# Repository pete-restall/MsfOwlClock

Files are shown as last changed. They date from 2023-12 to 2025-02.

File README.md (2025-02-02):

# MSF Owl Clock
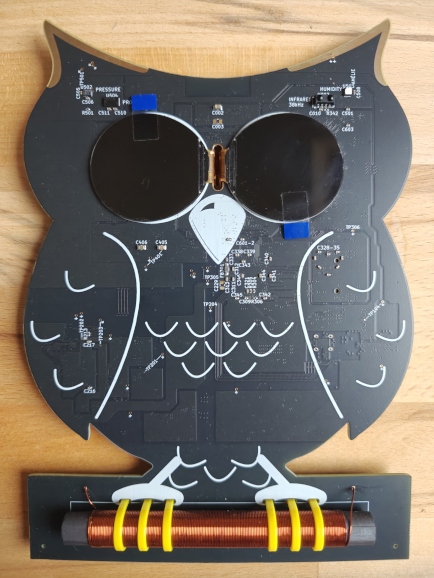
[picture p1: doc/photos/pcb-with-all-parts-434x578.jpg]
PCB
<span style="display:block;text-align:center"></span>

The board with the ferrite rod antenna and two TFT displays attached.

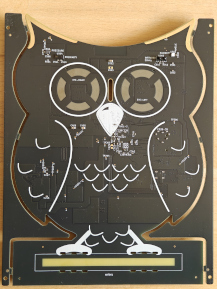
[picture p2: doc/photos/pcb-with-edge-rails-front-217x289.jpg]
Front of PCB
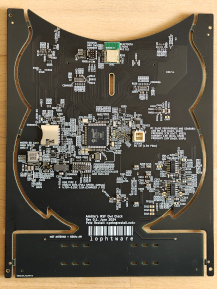
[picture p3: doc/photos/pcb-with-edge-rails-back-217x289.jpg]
Back of PCB
 

The above images are the boards as delivered from fabrication, not the end product.  Namely:
* The edge / tool rails need to be cut off to leave only the owl-shaped board
* A ferrite rod antenna (and tuning capacitors) need to be attached, creating a branch on which the owl perches (yellow tie-wraps for talons)
* Two TFT displays need to be secured in place for the eyes
* A base / stand needs to be 3D printed, which will also hold a speaker and its cavity

This project is a desk clock intended to synchronise with the [60kHz AM MSF](doc/datasheets/msf/msf.pdf) time signal that is broadcast by the UK's NPL using their [Anthorn Radio Station in Cumbria, England](https://www.npl.co.uk/msf-signal).

The [board schematics](src/schematics/msf-owl-clock.pdf) and [PCB fab files](src/pcb-fab/) were created in KiCAD.  [Firmware](src/firmware/) will, no doubt, be a very long-running part of the project (as usually seems to happen...)

The board consists of:
* A [PIC32CX1025SG41100](doc/datasheets/mcu/PIC32CX1025SG41100-datasheet-DS60001715.pdf) ARM Cortex M4F:
  * M-profile ARM v7 CPU running up to 120MHz
  * 1MiB flash
  * 256KiB SRAM
  * 8KiB backup SRAM
  * 1Msps 12-bit ADC
  * 1Msps 12-bit DAC
* Two multiplexed QSPI [360x360 Circular TFTs](doc/datasheets/tft/buydisplay-ER-TFT1.32-1.pdf) for the eyes
* A USB Type-C connector with USB PD / charger detection and USB2.0 Full Speed data
* A Micro SD Card connector
* An [IS31AP4991A](doc/datasheets/opamps/IS31AP4991A-SLS2-TR.pdf) audio amplifier / speaker driver (the speaker and cavity will be built into a 3D-printed base / stand)
* A [BC805M](doc/datasheets/bluetooth/BC805M.pdf) 2.4GHz Bluetooth / BLE 5.2 Module running an [nRF52805](doc/datasheets/bluetooth/nRF52805_PS_v1.4.pdf) ARM Cortex M4
* A range of I<sup>2</sup>C sensors:
  * A [DPS310XTSA1](doc/datasheets/sensors/pressure/DPS310XTSA1.pdf) Pressure Sensor to create a barometer
  * A [HDC3022](doc/datasheets/sensors/humidity/HDC3022.pdf) Humidity Sensor for measuring humidity and temperature
  * A [VL6180V1NR](doc/datasheets/sensors/proximity/VL6180V1NR-1.pdf) Proximity Sensor to allow power-saving mode when nobody is nearby / at night
  * A [TSOP75338TT](doc/datasheets/sensors/infrared/TSOP75338TT.pdf) 38kHz Infrared Receiver to allow remote control

The board is shaped as an owl as it is intended for my daughter, a little girl that _really_ likes owls.  I hope it will spark some curiosity and prompt her to enquire how everyday items and systems around her work, things that most people take for granted or do not even notice.

Obviously it's also for me to play with, as and when I get the time.

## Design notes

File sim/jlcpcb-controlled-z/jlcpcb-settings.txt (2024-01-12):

***
*** These settings correlate well with JLCPCB's impedance calculations for
*** stackup JLC04161H-7628:
***     https://jlcpcb.com/pcb-impedance-calculator/
***
*** The laminate parameters used can be found here:
***     https://jlcpcb.com/help/article/263-User-Guide-to-the-JLCPCB-Impedance-Calculator
***
*** A copy is also in the doc/datasheets/pcb directory.
***

-------------------------------

2D Impedance Calculator Program

Version 0.2.1.88

Time: Fri Jan 12 10:31:19 2024

GPL Version 2.0

-------------------------------

Simulation pix map 416 pixels high by 900 pixels wide.

1124224 bytes allocated for bmp.

Writing BMP file:

mdtlc_24001238880.bmp

INPUT PARAMETERS:

      Layer             Thick   Specifications 

       Solder Mask Top   1.20    Opening w=0.0  offset=0.0

        Signal Layer 1   1.60  Width=6.0  Etchback=0.16

      Laminate Layer 2   8.60    Resin Content  49.0% 4.0-4.4 

   Copper Plane Bottom   0.60    Opening w=0.0  offset=0.0

      Layer             Thick   Er    Loss Tangent

               Air top  29.60  1.00    0.00000

       Solder Mask Top   1.20  3.80    0.00200

        Signal Layer 1   1.60  4.20    0.00120

      Laminate Layer 2   8.60  4.20    0.00120

   Copper Plane Bottom   0.60  3.99

 Rdc_trace_1= 72.63  milliohms/in 20C

 DC resistance by pixel count:

 Rdc_trace_1=  72.511 milliohm/in.

 C          =   2.044 pF/in        L =  10.712 nH/in.

 Er         =   3.050       Loss_tan =   0.00113

 Zo         =  72.396 Ohms     Delay = 147.958 ps/in.

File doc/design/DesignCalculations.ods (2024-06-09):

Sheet: Capacitors
 |  |  | GRM21BR71A106KA73L | GRM155Z71A105KE01 | GRM155Z71A105KE01J | CL10B225KP8NNNC | CL05B104KA5NNNC | CL05A475MP5NRN
Capacitance
Nominal | 4.7 |  | 10 | 4.7 | 1 | 2.2 | 100 | 4.7
Nominal Adjusted for DC Bias | 1.88 | Look at the datasheet graphs for this; dependent on bias voltage and physical size | 6.83uF@3.3V, 4.73uF@5V | 3.972uF@3.3V, 3.212uF@5V | 0.598uF@3.3V | 1.95uF@3.3V | 92nF@5V | 1.88uF@3.3V
Min (-) Initial Tolerance (%) | 20.00% |  | 10.00% | 10.00% | 0.1 | 0.1 | 0.1 | 0.2
Max (+) Initial Tolerance (%) | 20.00% |  | 10.00% | 10.00% | 0.1 | 0.1 | 0.1 | 0.2
Min (-) Temperature Coefficient (%) | 15.00% | X7R and X5R are +/- 15% | 15.00% | 15.00% | 0.15 | 0.15 | 0.15 | 0.15
Max (+) Temperature Coefficient (%) | 15.00% |  | 15.00% | 15.00% | 0.15 | 0.15 | 0.15 | 0.15
Min Initial Capacitance | 1.504 |  | 6.147 | 3.5748 | 0.5382 | 1.755 | 82.8 | 1.504
Max Initial Capacitance | 2.256 |  | 7.513 | 4.3692 | 0.6578 | 2.145 | 101.2 | 2.256
Min Capacitance | 1.222 |  | 5.1225 | 2.979 | 0.4485 | 1.4625 | 69 | 1.222
Max Capacitance | 2.538 |  | 8.5375 | 4.965 | 0.7475 | 2.4375 | 115 | 2.538
Leakage Current
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

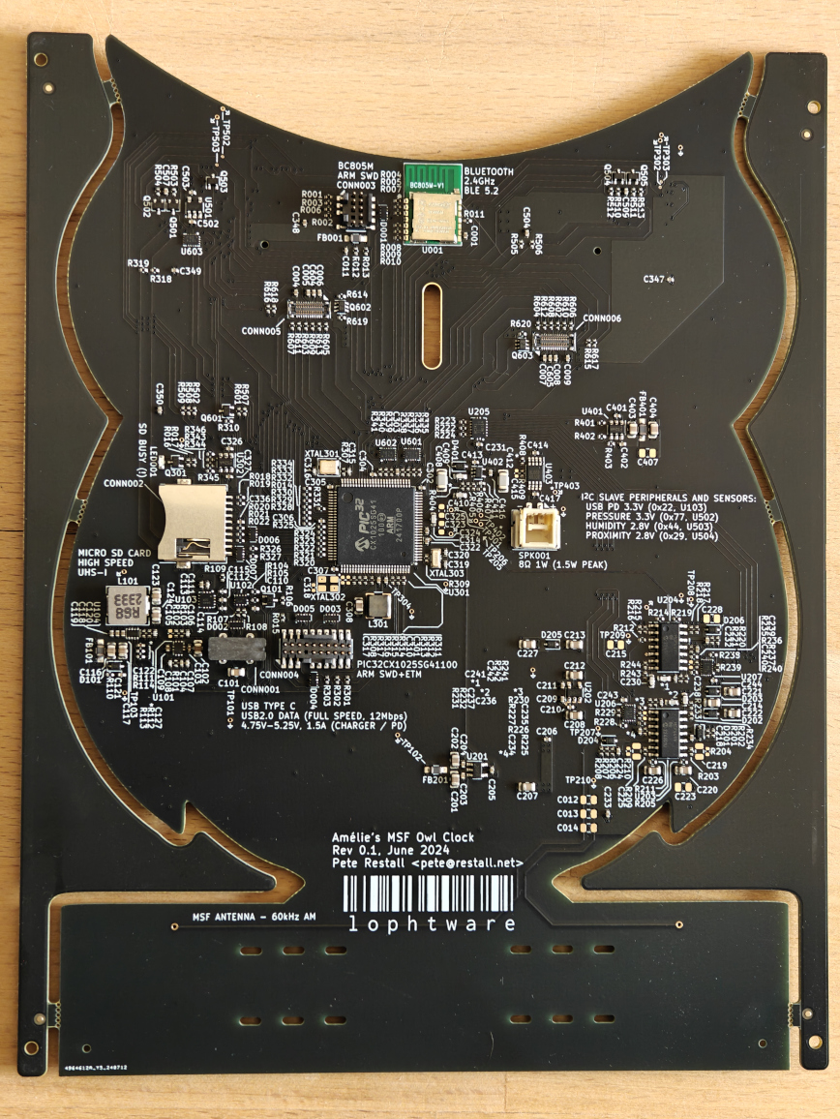
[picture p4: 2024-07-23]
doc/photos/pcb-with-edge-rails-back-868x1156.jpg

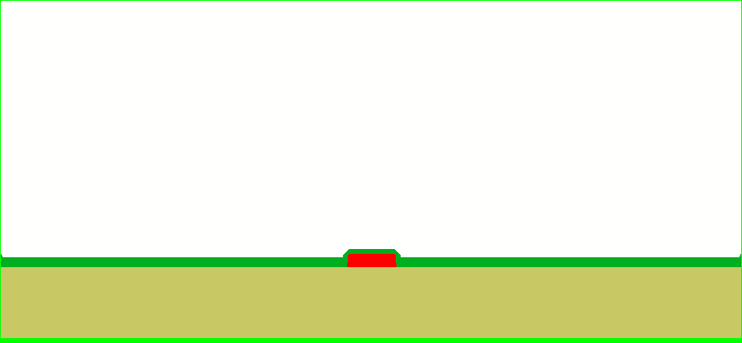
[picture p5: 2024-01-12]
sim/jlcpcb-controlled-z/6mil-single-microstrip.bmp

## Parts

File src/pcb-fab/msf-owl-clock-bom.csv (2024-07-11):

Designators | Value | Footprint | Package | Label | Manufacturer | Comment | Quantity | Description
C001, C004, C005, C006, C007, C008, C009, C010, C109, C110, C112, C113, C118, C119, C120, C121, C203, C204, C205, C206, C209, C210, C211, C216, C217, C218, C224, C231, C232, C233, C234, C239, C243, C244, C301, C302, C303, C304, C305, C306, C307, C309, C310, C311, C312, C313, C314, C322, C326, C327, C328, C329, C330, C331, C332, C333, C334, C335, C336, C337, C338, C339, C340, C341, C342, C343, C344, C345, C346, C347, C348, C349, C350, C401, C402, C413, C414, C416, C417, C501, C502, C503, C504, C505, C506, C507, C508, C509, C510, C511, C601, C602, C603, C604, C605 | 4.7μF | unpolarised-nominal-0402-1005 | 0402 | 4.7μF±20% 10V X5R | Samsung | CL05A475MP5NRNC | 95 | CL05A475MP5NRNC 4.7μF±20% 10V X5R 4.7μF 0402 Samsung
C002, C116, C117, C123, C124, C201, C202, C207, C208, C212, C213, C214, C220, C221, C222, C226, C227, C308, C403, C404, C405, C406 | 22μF | unpolarised-nominal-0805-2012 | 0805 | 22μF±20% 10V X5R | Samsung | CL21A226MPQNNN | 22 | CL21A226MPQNNN 22μF±20% 10V X5R 22μF 0805 Samsung
C230, C238, C409, C410 | 4.7nF | unpolarised-nominal-0603-1608 | 0603 | 4.7nF±5% 10V C0G | Murata | GCM1885C1H472GA16D | 4 | GCM1885C1H472GA16D 4.7nF±5% 10V C0G 4.7nF 0603 Murata
C011, C107, C321 | 100nF | unpolarised-nominal-0402-1005 | 0402 | 100nF±20% 10V X5R | Samsung | CL05B104KA5NNNC | 3 | CL05B104KA5NNNC 100nF±20% 10V X5R 100nF 0402 Samsung
C103, C104, C111 | 100nF | unpolarised-nominal-0402-1005 | 0402 | 100nF±20% 25V X5R | Samsung | CL05B104KA5NNNC | 3 | CL05B104KA5NNNC 100nF±20% 25V X5R 100nF 0402 Samsung
C236, C241, C324 | 4.7nF | unpolarised-nominal-0603-1608 | 0603 | 4.7nF±2% 10V C0G | Yageo | GCM1885C1H472GA16D | 3 | GCM1885C1H472GA16D 4.7nF±2% 10V C0G 4.7nF 0603 Murata
C101, C102 | 4.7μF | unpolarised-nominal-0805-2012 | 0805 | 4.7μF±10% 25V X5R | Samsung | CL21A475KAQNNNE | 2 | CL21A475KAQNNNE 4.7μF±10% 25V X5R 4.7μF 0805 Samsung
C114, C115 | 470pF | unpolarised-nominal-0402-1005 | 0402 | 470pF±10% 25V C0G | Murata | GCM1555C1H471FA16D | 2 | GCM1555C1H471FA16D 470pF±10% 25V C0G 470pF 0402 Murata
C237, C242 | 470pF | unpolarised-nominal-0402-1005 | 0402 | 470pF±2% 10V C0G | Murata | GCM1555C1H471FA16D | 2 | GCM1555C1H471FA16D 470pF±2% 10V C0G 470pF 0402 Murata
C315, C316 | 13pF | unpolarised-nominal-0402-1005 | 0402 | 13pF±1% 10V C0G | Murata | GJM1555C1H130FB01D | 2 | GJM1555C1H130FB01D 13pF±1% 10V C0G 13pF 0402 Murata
C319, C320 | 16pF | unpolarised-nominal-0402-1005 | 0402 | 16pF±1% 10V C0G | Murata | GCM1555C1H160FA16D | 2 | GCM1555C1H160FA16D 16pF±1% 10V C0G 16pF 0402 Murata
C408, C412 | 100nF | unpolarised-nominal-1206-3216 | 1206 | 100nF±5% 10V C0G | Murata | GRM3195C1H104JA05D | 2 | GRM3195C1H104JA05D 100nF±5% 10V C0G 100nF 1206 Murata
C106 | 39pF | unpolarised-nominal-0402-1005 | 0402 | 39pF±10% 10V X5R | Yageo | CC0402JRNPO9BN390 | 1 | CC0402JRNPO9BN390 39pF±10% 10V X5R 39pF 0402 Yageo
C108 | 100pF | unpolarised-nominal-0402-1005 | 0402 | 100pF±10% 10V X5R | Cal-Chip | GMC04CG101G50NT | 1 | GMC04CG101G50NT 100pF±10% 10V X5R 100pF 0402 Cal-Chip
C122 | 47nF | unpolarised-nominal-0402-1005 | 0402 | 47nF±10% 10V X5R | Vishay | VJ0402Y473KXQCW1BC | 1 | VJ0402Y473KXQCW1BC 47nF±10% 10V X5R 47nF 0402 Vishay
C127 | 10pF | unpolarised-nominal-0402-1005 | 0402 | 10pF±5% 10V C0G | Würth Elektronik | 885012005007 | 1 | 885012005007 10pF±5% 10V C0G 10pF 0402 Würth Elektronik
C411 | 22pF | unpolarised-nominal-0402-1005 | 0402 | 22pF±5% 10V C0G | Murata | GCM1555C1H220FA16D | 1 | GCM1555C1H220FA16D 22pF±5% 10V C0G 22pF 0402 Murata
R104, R105, R106, R110, R111, R222, R223, R224, R310, R326, R327, R342, R343, R344, R401, R402, R501, R502, R507, R508, R509, R512, R513, R601, R602, R603, R604, R605, R606, R607, R608, R609, R610, R611, R612, R613, R614, R615, R616, R617, R618 | 33kΩ | nominal-0402-1005 | 0402 | 33kΩ±1% 0.0625W | Walsin | WR04X3302FTL | 41 | WR04X3302FTL 33kΩ±1% 0.0625W 33kΩ 0402 Walsin
R004, R005, R007, R008, R009, R010, R011, R018, R019, R020, R021, R022, R311, R312, R313, R314, R315, R316, R317, R320, R321, R322, R323, R324, R325, R330, R331, R332, R333, R334 | 43Ω | nominal-0402-1005 | 0402 | 43Ω±1% 0.0625W | Yageo | RC0402FR-0743RL | 30 | RC0402FR-0743RL 43Ω±1% 0.0625W 43Ω 0402 Yageo
R002, R003, R006, R012, R301, R302, R303, R304 | 10kΩ | nominal-0402-1005 | 0402 | 10kΩ±1% 0.0625W | Walsin | WR04X1002FTL | 8 | WR04X1002FTL 10kΩ±1% 0.0625W 10kΩ 0402 Walsin
R212, R213, R215, R216, R217, R218 | 2.49kΩ | nominal-0402-1005 | 0402 | 2.49kΩ±0.1% 0.0625W | Yageo | RT0402BRD072K49L | 6 | RT0402BRD072K49L 2.49kΩ±0.1% 0.0625W 2.49kΩ 0402 Yageo
R318, R319, R340, R341, R505, R506 | 1.8kΩ | nominal-0402-1005 | 0402 | 1.8kΩ±1% 0.0625W | Yageo | RC0402FR-071K8L | 6 | RC0402FR-071K8L 1.8kΩ±1% 0.0625W 1.8kΩ 0402 Yageo
R013, R014, R103, R305, R306 | 1kΩ | nominal-0402-1005 | 0402 | 1kΩ±1% 0.0625W | Walsin | WR04X1001FTL | 5 | WR04X1001FTL 1kΩ±1% 0.0625W 1kΩ 0402 Walsin
R102, R203, R209, R307, R309 | 0Ω | nominal-0402-1005 | 0402 | 0Ω±1% 0.0625W | Yageo | RC0402FR-070RL | 5 | RC0402FR-070RL 0Ω±1% 0.0625W 0Ω 0402 Yageo
R201, R202, R208, R220, R221 | 4.99kΩ | nominal-0402-1005 | 0402 | 4.99kΩ±0.1% 0.0625W | Yageo | RT0402BRD074K99L | 5 | RT0402BRD074K99L 4.99kΩ±0.1% 0.0625W 4.99kΩ 0402 Yageo
R335, R336, R337, R338, R339 | 41.2Ω | nominal-0402-1005 | 0402 | 41.2Ω±1% 0.0625W | Yageo | RC0402FR-0741R2L | 5 | RC0402FR-0741R2L 41.2Ω±1% 0.0625W 41.2Ω 0402 Yageo
R001, R015, R328, R329 | 330Ω | nominal-0402-1005 | 0402 | 330Ω±1% 0.0625W | Walsin | WR04X3300FTL | 4 | WR04X3300FTL 330Ω±1% 0.0625W 330Ω 0402 Walsin
R113, R404, R408, R409 | 19.6kΩ | nominal-0402-1005 | 0402 | 19.6kΩ±1% 0.0625W | Walsin | WR04X1962FTL | 4 | WR04X1962FTL 19.6kΩ±1% 0.0625W 19.6kΩ 0402 Walsin
R503, R504, R510, R511 | 100Ω | nominal-0402-1005 | 0402 | 100Ω±1% 0.0625W | Walsin | WR04X1000FTL | 4 | WR04X1000FTL 100Ω±1% 0.0625W 100Ω 0402 Walsin
R225, R227, R237 | 390Ω | nominal-0402-1005 | 0402 | 390Ω±1% 0.0625W | Yageo | RT0402BRD07390RL | 3 | RT0402BRD07390RL 390Ω±1% 0.0625W 390Ω 0402 Yageo
R229, R235, R239 | 2.49kΩ | nominal-0402-1005 | 0402 | 2.49kΩ±1% 0.0625W | Yageo | RT0402BRD072K49L | 3 | RT0402BRD072K49L 2.49kΩ±1% 0.0625W 2.49kΩ 0402 Yageo
R016, R017 | 390Ω | nominal-0402-1005 | 0402 | 390Ω±1% 0.0625W | Yageo | RC0402FR-07390RL | 2 | RC0402FR-07390RL 390Ω±1% 0.0625W 390Ω 0402 Yageo
R107, R108 | 2.2Ω | nominal-0402-1005 | 0402 | 2.2Ω±1% 0.0625W | Vishay | RMCF0402FT2R20 | 2 | RMCF0402FT2R20 2.2Ω±1% 0.0625W 2.2Ω 0402 Vishay
R109, R114 | 5.1kΩ | nominal-0402-1005 | 0402 | 5.1kΩ±1% 0.0625W | Walsin | WR04X5101FTL | 2 | WR04X5101FTL 5.1kΩ±1% 0.0625W 5.1kΩ 0402 Walsin
R205, R211 | 27Ω | nominal-0402-1005 | 0402 | 27Ω±1% 0.0625W | TE Connectivity | CPF0402B27RE1 | 2 | CPF0402B27RE1 27Ω±1% 0.0625W 27Ω 0402 TE Connectivity
R206, R207 | 4.3kΩ | nominal-0402-1005 | 0402 | 4.3kΩ±0.1% 0.0625W | Yageo | RT0402BRD074K3L | 2 | RT0402BRD074K3L 4.3kΩ±0.1% 0.0625W 4.3kΩ 0402 Yageo
R214, R219 | 68Ω | nominal-0402-1005 | 0402 | 68Ω±0.1% 0.0625W | Yageo | RT0402BRD0768RL | 2 | RT0402BRD0768RL 68Ω±0.1% 0.0625W 68Ω 0402 Yageo
R228, R238 | 1.24kΩ | nominal-0402-1005 | 0402 | 1.24kΩ±1% 0.0625W | Yageo | RT0402BRD071K24L | 2 | RT0402BRD071K24L 1.24kΩ±1% 0.0625W 1.24kΩ 0402 Yageo
R230, R240 | 4.99kΩ | nominal-0402-1005 | 0402 | 4.99kΩ±1% 0.0625W | Yageo | RT0402BRD074K99L | 2 | RT0402BRD074K99L 4.99kΩ±1% 0.0625W 4.99kΩ 0402 Yageo
R231, R241 | 4.12kΩ | nominal-0402-1005 | 0402 | 4.12kΩ±0.1% 0.0625W | Yageo | RT0402BRD074K12L | 2 | RT0402BRD074K12L 4.12kΩ±0.1% 0.0625W 4.12kΩ 0402 Yageo
R232, R242 | 64.9Ω | nominal-0402-1005 | 0402 | 64.9Ω±0.1% 0.0625W | TE Connectivity | RP73PF1E64R9BTD | 2 | RP73PF1E64R9BTD 64.9Ω±0.1% 0.0625W 64.9Ω 0402 TE Connectivity
R233, R243 | 49.9kΩ | nominal-0402-1005 | 0402 | 49.9kΩ±0.1% 0.0625W | Yageo | RT0402BRD0749K9L | 2 | RT0402BRD0749K9L 49.9kΩ±0.1% 0.0625W 49.9kΩ 0402 Yageo
R234, R244 | 0Ω | nominal-0402-1005 | 0402 | 0Ω±0.1% 0.0625W | Yageo | RC0402FR-070RL | 2 | RC0402FR-070RL 0Ω±0.1% 0.0625W 0Ω 0402 Yageo
R345, R405 | 5.1kΩ | nominal-0402-1005 | 0402 | 5.1kΩ±1% 0.0625W | Walsin | WR04X5101FTL | 2 | WR04X5101FTL 5.1kΩ±1% 0.0625W 5.1kΩ 0402 Walsin
R346, R407 | 39kΩ | nominal-0402-1005 | 0402 | 39kΩ±1% 0.0625W | Yageo | RC0402FR-0739KL | 2 | RC0402FR-0739KL 39kΩ±1% 0.0625W 39kΩ 0402 Yageo
R619, R620 | 18Ω | nominal-0402-1005 | 0402 | 18Ω±1% 0.0625W | Yageo | RC0402FR-0718RL | 2 | RC0402FR-0718RL 18Ω±1% 0.0625W 18Ω 0402 Yageo
R101 | 300kΩ | nominal-0402-1005 | 0402 | 300kΩ±1% 0.0625W | Yageo | RC0402FR-07300KL | 1 | RC0402FR-07300KL 300kΩ±1% 0.0625W 300kΩ 0402 Yageo
R112 | 88.7kΩ | nominal-0402-1005 | 0402 | 88.7kΩ±1% 0.0625W | Walsin | WR04X8872FTL | 1 | WR04X8872FTL 88.7kΩ±1% 0.0625W 88.7kΩ 0402 Walsin
R226 | 47Ω | nominal-0402-1005 | 0402 | 47Ω±1% 0.0625W | Panasonic | ERA-2AEB470X | 1 | ERA-2AEB470X 47Ω±1% 0.0625W 47Ω 0402 Panasonic
R236 | 100Ω | nominal-0402-1005 | 0402 | 100Ω±1% 0.0625W | Yageo | RT0402BRD07100RL | 1 | RT0402BRD07100RL 100Ω±1% 0.0625W 100Ω 0402 Yageo
R403 | 68kΩ | nominal-0402-1005 | 0402 | 68kΩ±0.1% 0.0625W | KOA Speer | RN73R1ETTP6802B25 | 1 | RN73R1ETTP6802B25 68kΩ±0.1% 0.0625W 68kΩ 0402 KOA Speer
R406 | 16kΩ | nominal-0402-1005 | 0402 | 16kΩ±1% 0.0625W | Yageo | RC0402FR-0716KL | 1 | RC0402FR-0716KL 16kΩ±1% 0.0625W 16kΩ 0402 Yageo
L101 | 680nH | 07A7 | 07A7 | 15.5A_{RMS} / 25A_{SAT}, 5.5mΩ±20% @ DC | Kyocera | LMLP07A7MR68DTAS | 1 | LMLP07A7MR68DTAS 15.5A_{RMS} / 25A_{SAT}, 5.5mΩ±20% @ DC 680nH 07A7 Kyocera
L301 | 10μH | HPC4018NF | HPC4018NF | 1.5A_{RMS} / 1.5A_{SAT}, 150mΩ±20% @ DC | Tai Tech | HPC4018NF-100M | 1 | HPC4018NF-100M 1.5A_{RMS} / 1.5A_{SAT}, 150mΩ±20% @ DC 10μH HPC4018NF Tai Tech
D101, D201, D202, D203, D204, D205, D206, D401 | SD103AWS | SOD323 | SOD323 |  | Evvo Semi | SD103AWS | 8 | SD103AWS SD103AWS SOD323 Evvo Semi
D001, D002, D003, D004, D005, D006, D007 | D5V0FS4U10LP | D5V0FS4U10LP | U-DFN2510-10 | V_{RWM}=5V V_{CL}=6V V_{BR}=7V C_{d}=0.45pF | Diodes Incorporated | D5V0FS4U10LP | 7 | D5V0FS4U10LP V_{RWM}=5V V_{CL}=6V V_{BR}=7V C_{d}=0.45pF D5V0FS4U10LP U-DFN2510-10 Diodes Incorporated
U601, U602, U603 | TMUX1574RSV | UQFN16-1.8x2.6mm-0.4mm | UQFN16 |  | Texas Instruments | TMUX1574RSVR | 3 | TMUX1574RSVR TMUX1574RSV UQFN16 Texas Instruments
U203, U204 | MCP6499 | SOIC14-3.9x8.65mm-1.27mm | SOIC |  | Microchip | MCP6499T-E-SL | 2 | MCP6499T-E-SL MCP6499 SOIC Microchip
U206, U207 | TMUX1511RSV | UQFN16-1.8x2.6mm-0.4mm | UQFN16 |  | Texas Instruments | TMUX1511RSVR | 2 | TMUX1511RSVR TMUX1511RSV UQFN16 Texas Instruments
U302, U401 | AP22653AW6 | SOT26 | SOT26 |  | Diodes Incorporated | AP22653AW6-7 | 2 | AP22653AW6-7 AP22653AW6 SOT26 Diodes Incorporated
U001 | BC805M | BC805M | BC805M |  | Fanstel | BC805M | 1 | BC805M BC805M BC805M Fanstel
U002 | TSOP75338TT | TSOP7????TT | TSOP753 |  | Vishay | TSOP75338TT | 1 | TSOP75338TT TSOP75338TT TSOP753 Vishay
U101 | MP5016HGQH | QFN10-1.5x2.0mm-0.5mm | QFN10 |  | Monolithic Power Solutions | MP5016HGQH | 1 | MP5016HGQH MP5016HGQH QFN10 Monolithic Power Solutions
U102 | BQ24392RSER | UQFN10-1.5x2.0mm-0.5mm | UQFN10 |  | Texas Instruments | BQ24392RSER | 1 | BQ24392RSER BQ24392RSER UQFN10 Texas Instruments
U103 | FUSB302BMPX | WQFN14-2.5x2.5mm-0.5mm-expad-1.45x1.45mm-thermvias | WQFN14 |  | ON Semiconductor | FUSB302BMPX | 1 | FUSB302BMPX FUSB302BMPX WQFN14 ON Semiconductor
U104 | TPS628512DRLR | SOT583 | SOT583 |  | Texas Instruments | TPS628512DRLR | 1 | TPS628512DRLR TPS628512DRLR SOT583 Texas Instruments
U201 | TPS7A2042PDBVR | TPS7A20??PDBVR | SOT23 |  | Texas Instruments | TPS7A2042PDBVR | 1 | TPS7A2042PDBVR TPS7A2042PDBVR SOT23 Texas Instruments
U202 | TPS7A2036PDBVR | TPS7A20??PDBVR | SOT23 |  | Texas Instruments | TPS7A2036PDBVR | 1 | TPS7A2036PDBVR TPS7A2036PDBVR SOT23 Texas Instruments
U205 | 74HC595BQ | DHVQFN16-2.5x3.5mm-0.5mm-expad-2x1mm | DHVQFN16 |  | Nexperia | 74HC595BQ | 1 | 74HC595BQ 74HC595BQ DHVQFN16 Nexperia
U301 | PIC32CX1025SG41100-I/E5X | TQFP100-14x14mm-0.5mm | TQFP100 |  | Microchip | PIC32CX1025SG41100-I/E5X | 1 | PIC32CX1025SG41100-I/E5X PIC32CX1025SG41100-I/E5X TQFP100 Microchip
U402 | MCP6486U | SOT353 | SOT353 |  | Microchip | MCP6486UT-E-LT | 1 | MCP6486UT-E-LT MCP6486U SOT353 Microchip
U403 | IS31AP4991A-SLS2 | MSOP8-3x3mm-0.65mm | MSOP8 |  | Lumissil Microsystems | IS31AP4991A-SLS2-TR | 1 | IS31AP4991A-SLS2-TR IS31AP4991A-SLS2 MSOP8 Lumissil Microsystems
U501 | TPS7A2028PDBVR | TPS7A20??PDBVR | SOT23 |  | Texas Instruments | TPS7A2028PDBVR | 1 | TPS7A2028PDBVR TPS7A2028PDBVR SOT23 Texas Instruments
U502 | DPS310XTSA1 | PG-VLGA-8-1-2.0x2.5mm-0.65mm | PG-VLGA-8-1 |  | Infineon | DPS310XTSA1 | 1 | DPS310XTSA1 DPS310XTSA1 PG-VLGA-8-1 Infineon
U503 | HDC3022 | WSON8-2.5x2.5mm-0.5mm-expad-1.2x1.9mm-thermvias | WSON8 |  | Texas Instruments | HDC3022DEJR | 1 | HDC3022DEJR HDC3022 WSON8 Texas Instruments
U504 | VL6180V1NR1 | OPTICAL-LGA12-2.8x4.8mm-0.75mm | LGA12 |  | ST Microelectronics | VL6180V1NR1-1 | 1 | VL6180V1NR1-1 VL6180V1NR1 LGA12 ST Microelectronics
Q101, Q301, Q501, Q502, Q503, Q504, Q505, Q601 | NX6008NBKW | SOT323 | SOT323 |  | Nexperia | NX6008NBKW | 8 | NX6008NBKW NX6008NBKW SOT323 Nexperia
FB001, FB201, FB301 | WLBD2012HCU601TH | WLBD2012 | WLBD2012 | 2A, 90mΩ @ DC, 600Ω±25% @ 100MHz | Walsin Technology | WLBD2012HCU601TH | 3 | WLBD2012HCU601TH 2A, 90mΩ @ DC, 600Ω±25% @ 100MHz WLBD2012HCU601TH WLBD2012 Walsin Technology
FB101, FB401 | WLBD2012HCU121TH | WLBD2012 | WLBD2012 | 5A, 20mΩ @ DC, 120Ω±25% @ 100MHz | Walsin Technology | WLBD2012HCU121TH | 2 | WLBD2012HCU121TH 5A, 20mΩ @ DC, 120Ω±25% @ 100MHz WLBD2012HCU121TH WLBD2012 Walsin Technology
Q602, Q603 | BC847BS | SOT363 | SOT363 |  | Diodes Incorporated | BC847BS-7-F | 2 | BC847BS-7-F BC847BS SOT363 Diodes Incorporated
LED001 | SD Card Busy | nominal-0603-1608 | 0603 |  | Harvatek | B1931USD-20D000814U1930 | 1 | B1931USD-20D000814U1930 SD Card Busy 0603 Harvatek
SPK001 | Header (Molex 502443-0270) | 502443-0270 | 502443-0270 |  | Molex | 502443-0270 | 1 | 502443-0270 Header (Molex 502443-0270) 502443-0270 Molex
XTAL301 | 24MHz | 3225-1-3 | 3225 | 24MHz±10ppm @ 12pF (AT) | Raltron | RH100-24.000-12-1010-EXT-TR | 1 | RH100-24.000-12-1010-EXT-TR 24MHz±10ppm @ 12pF (AT) 24MHz 3225 Raltron
XTAL303 | 32.768kHz | 3215 | 3215 | 32.768kHz±20ppm @ 12.5pF (Tuning Fork) | Raltron | RT3215-32.768-12.5-TR-10PPM | 1 | RT3215-32.768-12.5-TR-10PPM 32.768kHz±20ppm @ 12.5pF (Tuning Fork) 32.768kHz 3215 Raltron
CONN005, CONN006 | EastRising ER-TFT1.32-1 | OK-14GF024-04 | OK-14GF024-04 |  | EastRising | OK-14GF024-04 | 2 | OK-14GF024-04 EastRising ER-TFT1.32-1 OK-14GF024-04 EastRising
CONN001 | GSB1CA11101DSHR | GSB1CA11101DSHR | GSB1CA11101DSHR |  | Amphenol | GSB1CA11101DSHR | 1 | GSB1CA11101DSHR GSB1CA11101DSHR GSB1CA11101DSHR Amphenol
CONN002 | MSD-11-A | MSD-11-A | MSD-11-A |  | CUI Devices | MSD-11-A | 1 | MSD-11-A MSD-11-A MSD-11-A CUI Devices
CONN003 | Cortex-M Debug Header | FTSH-105-?-?-DV-007-?-? | FTSH-105-01-L-DV-007-K |  | Samtec | FTSH-105-01-L-DV-007-K | 1 | FTSH-105-01-L-DV-007-K Cortex-M Debug Header FTSH-105-01-L-DV-007-K Samtec
CONN004 | Cortex-M Debug Header with ETM | FTSH-110-01-?-DV-007-?-? | FTSH-110-01-F-DV-007-K |  | Samtec | FTSH-110-01-F-DV-007-K | 1 | FTSH-110-01-F-DV-007-K Cortex-M Debug Header with ETM FTSH-110-01-F-DV-007-K Samtec

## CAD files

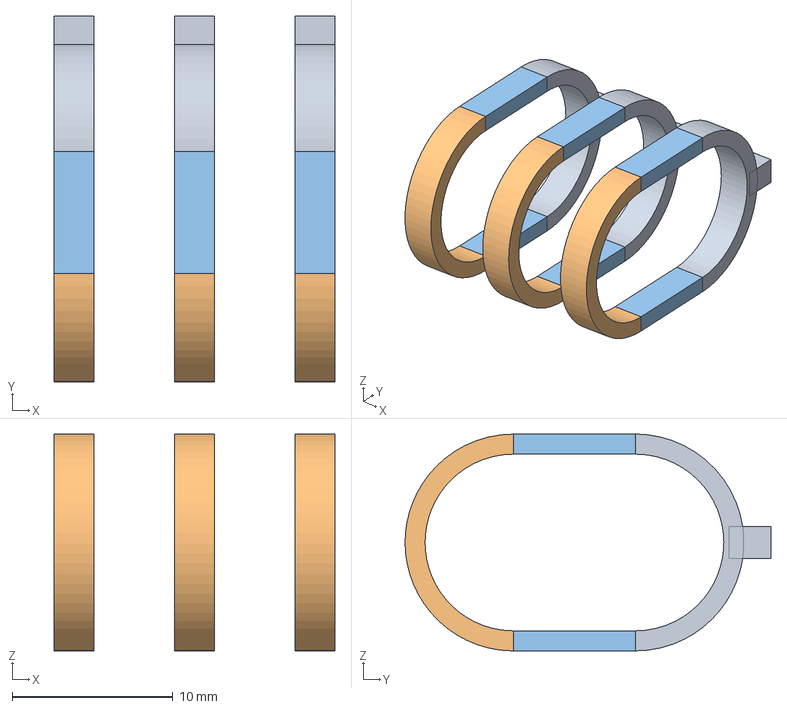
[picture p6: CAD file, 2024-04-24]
src/models/talon/talon.step
17.5 x 22.8 x 13.5 mm

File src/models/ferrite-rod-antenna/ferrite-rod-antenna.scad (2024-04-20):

function mm(x) = x;

module ferriteRod(length, diameter) {
	color("#000000")
		rotate([0, 90, 0])
		difference() {
			radius = diameter / 2;
			translate([0, 0, -length / 2])
				linear_extrude(length)
				circle(d=diameter, $fn=360);

			translate([0, radius, 0])
				cube([diameter, mm(2), length + 1], center=true);

			translate([0, -radius, 0])
				cube([diameter, mm(2), length + 1], center=true);
		}
}

module copperLoop(loopDiameter, wireDiameter) {
	color("#f7703b")
		rotate([0, 90, 0])
		rotate_extrude(convexity=10, $fn=10)
		translate([loopDiameter / 2 + wireDiameter, 0, 0])
			circle(r=wireDiameter, $fn=10);
}

module copperLoops(turns) {
	wireDiameter = mm(0.5);
	halfLength = wireDiameter * (turns / 2);
	for (x = [-halfLength : wireDiameter : halfLength]) {
		translate([x, 0, 0])
			copperLoop(loopDiameter=mm(10), wireDiameter=wireDiameter);
	}
}

ferriteRod(length=mm(100), diameter=mm(10));
//copperLoops(turns=164);

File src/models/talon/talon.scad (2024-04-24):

function mm(x) = x;

module tiewrapFlatHalfLoop(loopInnerDiameter, tiewrapThickness) {
	loopOuterDiameter = loopInnerDiameter + tiewrapThickness * 2;
	loopOuterRadius = loopOuterDiameter / 2;
	difference() {
		circle(d=loopOuterDiameter, $fn=60);

		circle(d=loopInnerDiameter, $fn=60);

		translate([0, loopOuterRadius, 0])
			square([loopOuterDiameter, loopOuterDiameter], center=true);
	}
}

module tiewrapFlat(loopInnerDiameter, loopStretch, tiewrapThickness) {
	loopOuterDiameter = loopInnerDiameter + tiewrapThickness * 2;
	loopOuterRadius = loopOuterDiameter / 2;
	loopInnerRadius = loopInnerDiameter / 2;
	union() {
		translate([0, -loopStretch / 2, 0])
		tiewrapFlatHalfLoop(loopInnerDiameter, tiewrapThickness);

		translate([0, loopStretch / 2, 0])
			rotate([0, 0, 180])
			tiewrapFlatHalfLoop(loopInnerDiameter, tiewrapThickness);

		translate([loopInnerRadius + tiewrapThickness / 2, 0, 0])
			square([tiewrapThickness, loopStretch], center=true);

		translate([-loopInnerRadius - tiewrapThickness / 2, 0, 0])
			square([tiewrapThickness, loopStretch], center=true);
	}
}

module tiewrapLoop(loopInnerDiameter, loopStretch, tiewrapWidth, tiewrapThickness) {
	lockDepth = mm(2);
	lockHeight = mm(2);
	color("#ffff00")
		union() {
			translate([0, loopInnerDiameter / 2 + tiewrapThickness + loopStretch / 2	 + (lockDepth - tiewrapThickness) / 2, 0])
				cube([tiewrapWidth, lockDepth + tiewrapThickness / 2, lockHeight], center=true);

			rotate([0, 90, 0])
				linear_extrude(tiewrapWidth, center=true)
				tiewrapFlat(loopInnerDiameter, loopStretch, tiewrapThickness);
		}
}

for (x = [ -mm(7.5) : mm(7.5) : mm(7.5) ]) {
	translate([x, 0, 0])
		tiewrapLoop(loopInnerDiameter=mm(11), loopStretch=mm(1.6 + 12 / 2), tiewrapWidth=mm(2.5), tiewrapThickness=mm(1.25));
}

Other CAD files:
src/models/ferrite-rod-antenna/ferrite-rod-antenna.step
src/models/ferrite-rod-antenna/ferrite-rod-antenna.FCStd
src/models/talon/talon.FCStd

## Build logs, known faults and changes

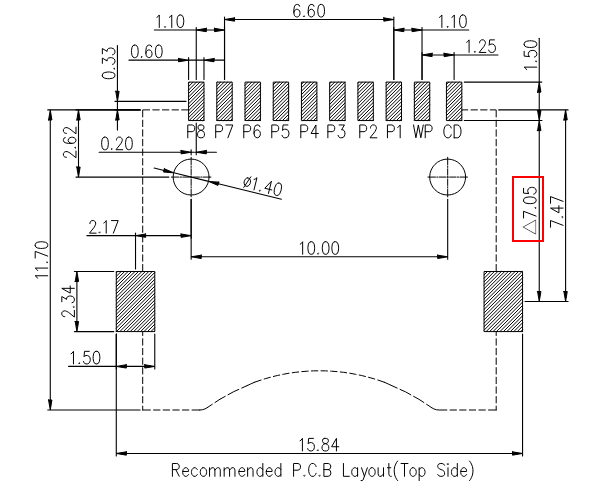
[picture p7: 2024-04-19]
doc/datasheets/connectors/MSD-11-A-footprint-errata.png

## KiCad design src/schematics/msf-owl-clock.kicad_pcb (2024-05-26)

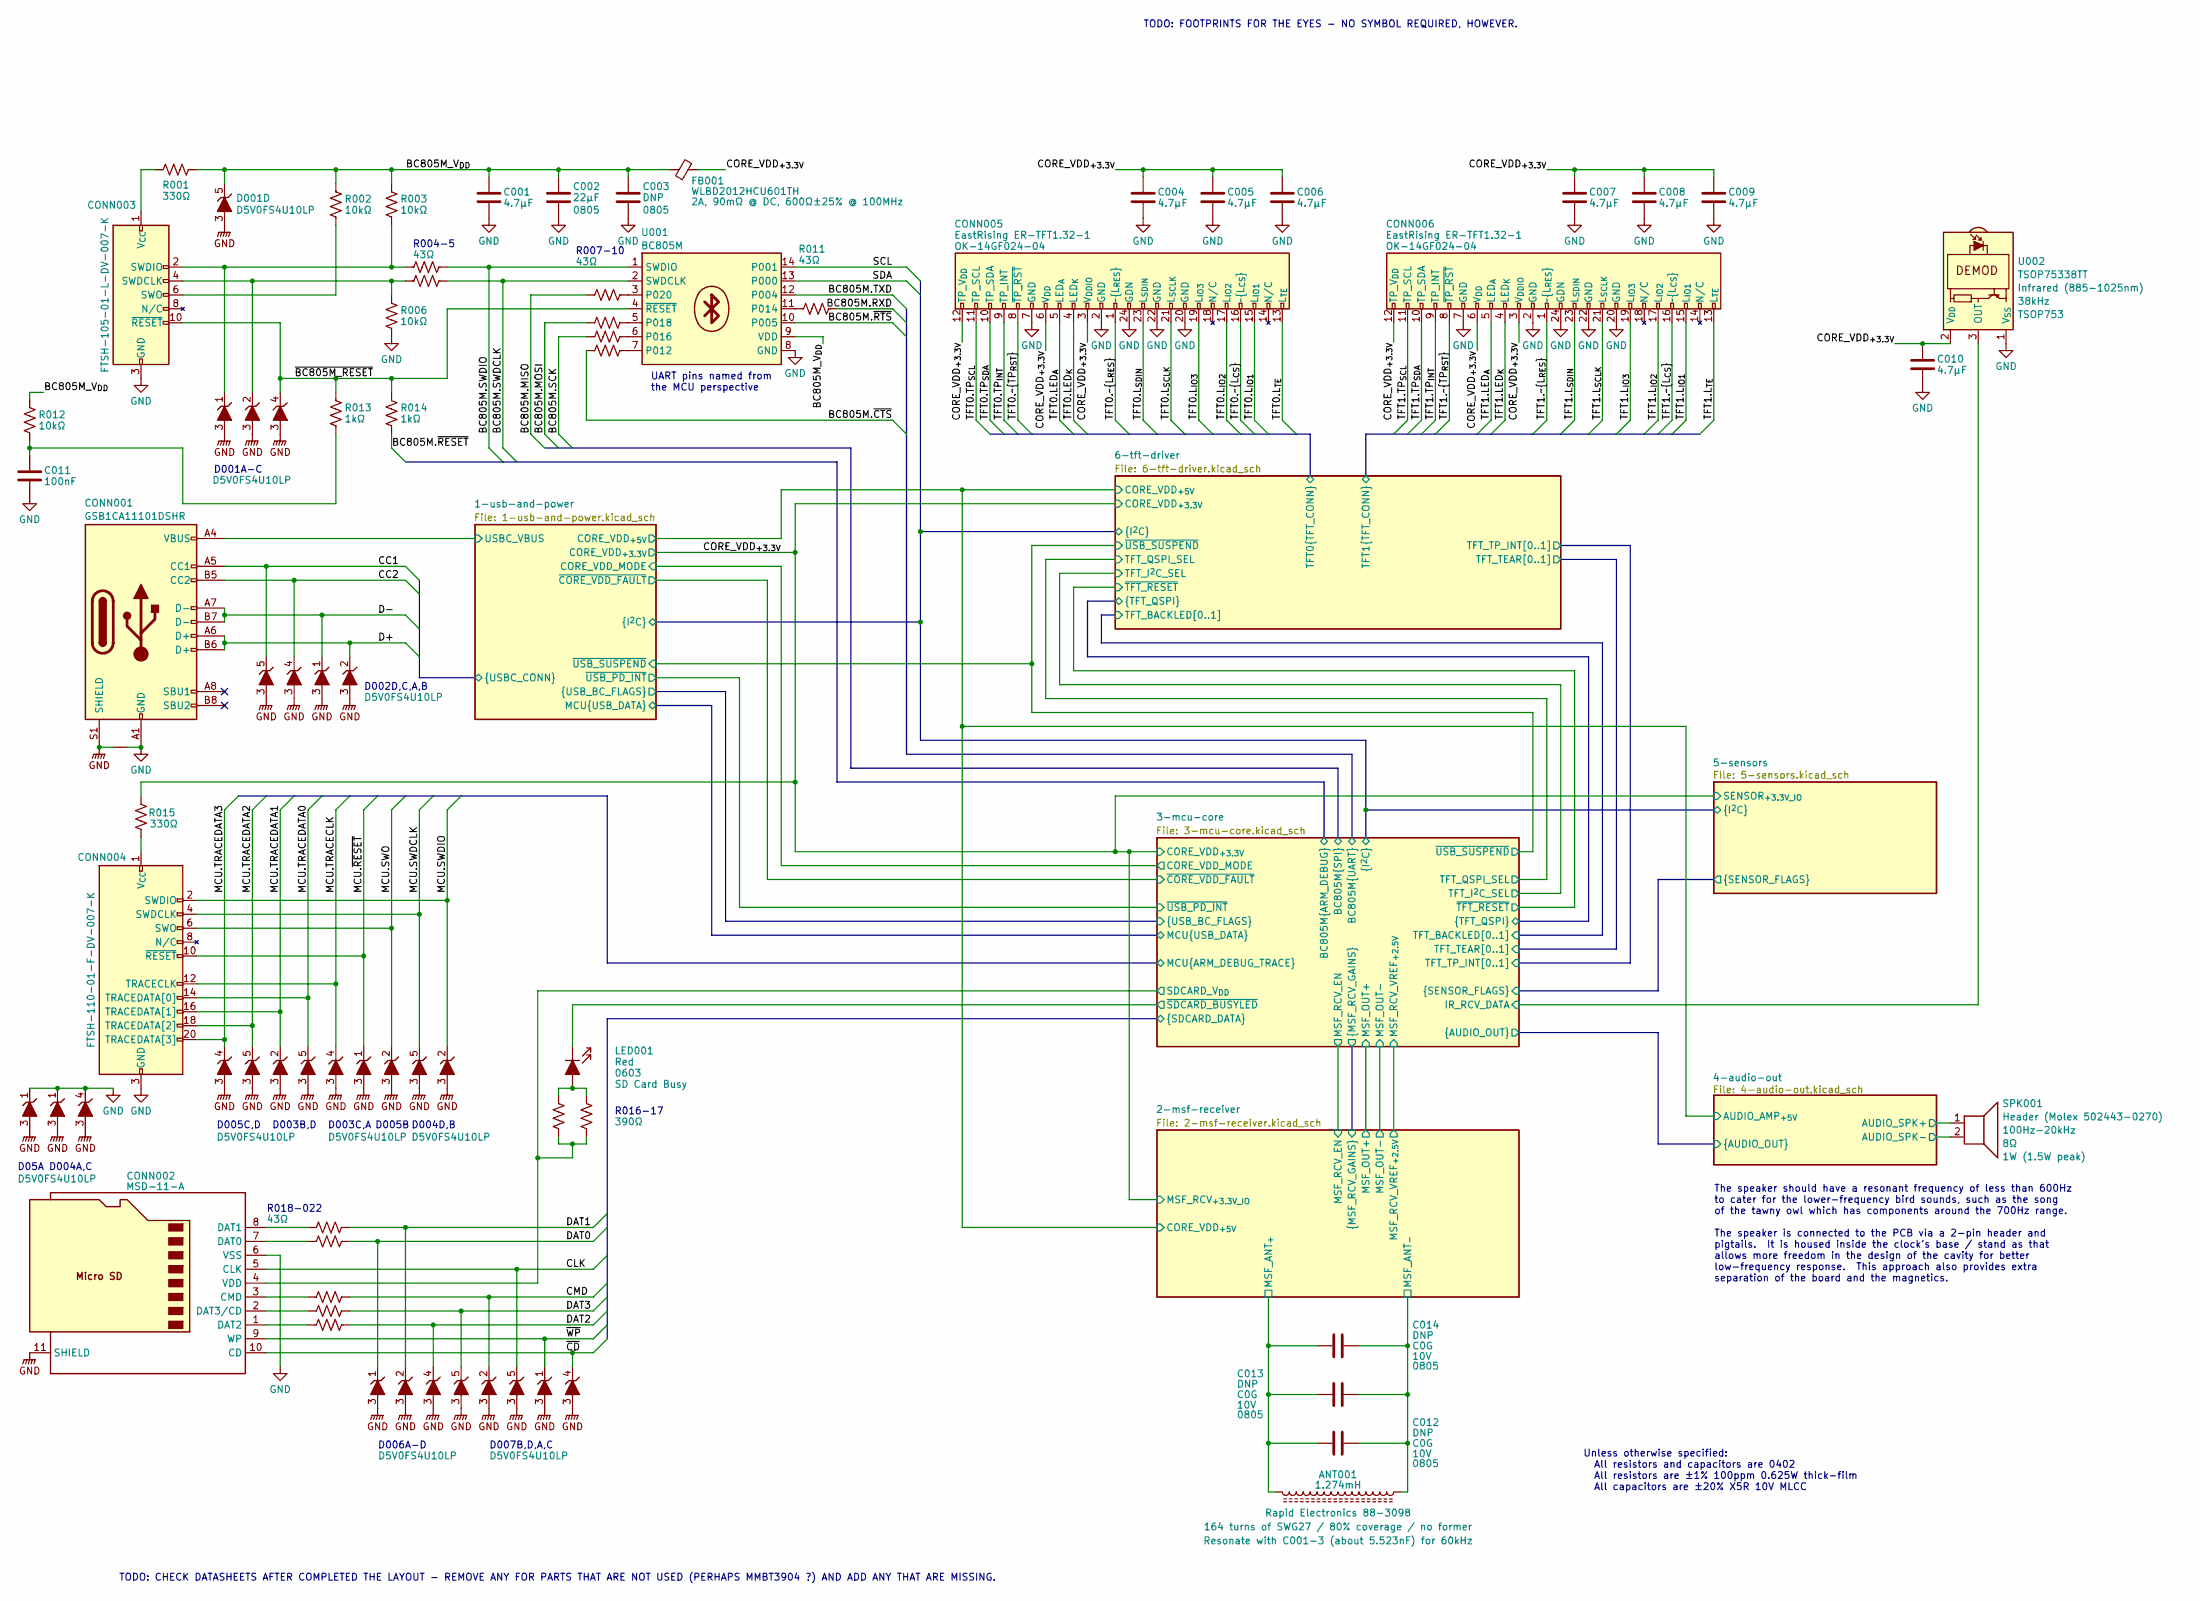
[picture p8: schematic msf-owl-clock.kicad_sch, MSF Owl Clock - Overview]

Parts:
ANT001: 1.274mH; ferrite-rod-antenna; ManufacturerPartNumber Rapid Electronics 88-3098
C001, C004, C005, C006, C007, C008, C009, C010: 4.7μF; unpolarised-nominal-0402-1005; Tolerance ±20%; VoltageRating 10V; ManufacturerPartNumber CL05A475MP5NRNC
C002: 22μF; unpolarised-nominal-0805-2012; Tolerance ±20%; VoltageRating 10V; ManufacturerPartNumber CL21A226MPQNNN
C003: DNP; unpolarised-nominal-0805-2012; Tolerance ±20%; VoltageRating 10V; ManufacturerPartNumber CL21A226MPQNNN
C011: 100nF; unpolarised-nominal-0402-1005; Tolerance ±20%; VoltageRating 10V; ManufacturerPartNumber CL05B104KA5NNNC
C012, C013, C014: DNP; unpolarised-nominal-0805-2012; VoltageRating 10V
CONN001: GSB1CA11101DSHR; ManufacturerPartNumber GSB1CA11101DSHR
CONN002: MSD-11-A; ManufacturerPartNumber MSD-11-A
CONN003: Cortex-M Debug Header; FTSH-105-?-?-DV-007-?-?; ManufacturerPartNumber FTSH-105-01-L-DV-007-K
CONN004: Cortex-M Debug Header with ETM; FTSH-110-01-?-DV-007-?-?; ManufacturerPartNumber FTSH-110-01-F-DV-007-K
CONN005, CONN006: EastRising ER-TFT1.32-1; OK-14GF024-04; ManufacturerPartNumber OK-14GF024-04
D001, D002, D003, D004, D005, D006, D007: D5V0FS4U10LP; ManufacturerPartNumber D5V0FS4U10LP
FB001: WLBD2012HCU601TH; WLBD2012; Tolerance ±25%; ManufacturerPartNumber WLBD2012HCU601TH
LED001: SD Card Busy; nominal-0603-1608; ManufacturerPartNumber B1931USD-20D000814U1930
NT001: Net Tie; net-tie-2-6mil
R001, R015: 330Ω; nominal-0402-1005; Tolerance ±1%; ManufacturerPartNumber WR04X3300FTL
R002, R003, R006, R012: 10kΩ; nominal-0402-1005; Tolerance ±1%; ManufacturerPartNumber WR04X1002FTL
R004, R005, R007, R008, R009, R010, R011, R018, R019, R020, R021, R022: 43Ω; nominal-0402-1005; Tolerance ±1%; ManufacturerPartNumber RC0402FR-0743RL
R013, R014: 1kΩ; nominal-0402-1005; Tolerance ±1%; ManufacturerPartNumber WR04X1001FTL
R016, R017: 390Ω; nominal-0402-1005; Tolerance ±1%; ManufacturerPartNumber RC0402FR-07390RL
SHEET001, SHEET002, SHEET003, SHEET004, SHEET005, SHEET006: (no value)
SPK001: Header (Molex 502443-0270); 502443-0270; Rating 1W (1.5W peak); ManufacturerPartNumber AC0402DR-0716KL
U001: BC805M; ManufacturerPartNumber BC805M
U002: TSOP75338TT; TSOP7????TT; ManufacturerPartNumber TSOP75338TT

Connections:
/1-usb-and-power/CC1: CONN001.A5 (CC1), D002.5 (K), D002.6; also elsewhere on the board
/1-usb-and-power/CC2: CONN001.B5 (CC2), D002.4 (K), D002.7; also elsewhere on the board
/1-usb-and-power/CORE_VDD_{+5V}: CONN005.5 (LED_{A}), CONN006.5 (LED_{A}); also elsewhere on the board
/1-usb-and-power/D+: CONN001.A6 (D+), CONN001.B6 (D+), D002.2 (K), D002.9; also elsewhere on the board
/1-usb-and-power/D-: CONN001.A7 (D-), CONN001.B7 (D-), D002.1 (K), D002.10; also elsewhere on the board
/1-usb-and-power/SCL: U001.14 (P001); also elsewhere on the board
/1-usb-and-power/SDA: U001.13 (P000); also elsewhere on the board
/1-usb-and-power/USBC_VBUS: CONN001.A4 (VBUS), CONN001.A9 (VBUS), CONN001.B4 (VBUS), CONN001.B9 (VBUS); also elsewhere on the board
/2-msf-receiver/MSF_ANT_{+}: ANT001.1, C012.1, C013.1, C014.1; also elsewhere on the board
/2-msf-receiver/MSF_RCV_VREF_{+1.8V}: ANT001.2, C012.2, C013.2, C014.2; also elsewhere on the board
/3-mcu-core/BC805M.MISO: R007.1; also elsewhere on the board
/3-mcu-core/BC805M.MOSI: R008.1; also elsewhere on the board
/3-mcu-core/BC805M.RXD: R011.2; also elsewhere on the board
/3-mcu-core/BC805M.SCK: R009.1; also elsewhere on the board
/3-mcu-core/BC805M.SWDCLK: R005.2, U001.2 (SWDCLK); also elsewhere on the board
/3-mcu-core/BC805M.SWDIO: R004.2, U001.1 (SWDIO); also elsewhere on the board
/3-mcu-core/BC805M.TXD: U001.12 (P004); also elsewhere on the board
/3-mcu-core/BC805M.~CTS: R010.1; also elsewhere on the board
/3-mcu-core/BC805M.~RESET: R014.2; also elsewhere on the board
/3-mcu-core/BC805M.~RTS: U001.10 (P005); also elsewhere on the board
/3-mcu-core/CLK: CONN002.5 (CLK), D007.5 (K), D007.6; also elsewhere on the board
/3-mcu-core/CMD: D007.2 (K), D007.9, R020.2; also elsewhere on the board
/3-mcu-core/DAT0: D006.1 (K), D006.10, R019.2; also elsewhere on the board
/3-mcu-core/DAT1: D006.2 (K), D006.9, R018.2; also elsewhere on the board
/3-mcu-core/DAT2: D006.4 (K), D006.7, R022.2; also elsewhere on the board
/3-mcu-core/DAT3: D006.5 (K), D006.6, R021.2; also elsewhere on the board
/3-mcu-core/IR_RCV_DATA: U002.3 (OUT); also elsewhere on the board
/3-mcu-core/MCU.SWDCLK: CONN004.4 (SWDCLK), D004.5 (K), D004.6; also elsewhere on the board
/3-mcu-core/MCU.SWDIO: CONN004.2 (SWDIO), D004.2 (K), D004.9; also elsewhere on the board
/3-mcu-core/MCU.SWO: CONN004.6 (SWO), D005.2 (K), D005.9; also elsewhere on the board
/3-mcu-core/MCU.TRACECLK: CONN004.12 (TRACECLK), D003.4 (K), D003.7; also elsewhere on the board
/3-mcu-core/MCU.TRACEDATA0: CONN004.14 (TRACEDATA[0]), D003.5 (K), D003.6; also elsewhere on the board
/3-mcu-core/MCU.TRACEDATA1: CONN004.16 (TRACEDATA[1]), D003.2 (K), D003.9; also elsewhere on the board
/3-mcu-core/MCU.TRACEDATA2: CONN004.18 (TRACEDATA[2]), D005.5 (K), D005.6; also elsewhere on the board
/3-mcu-core/MCU.TRACEDATA3: CONN004.20 (TRACEDATA[3]), D005.4 (K), D005.7; also elsewhere on the board
/3-mcu-core/MCU.~RESET: CONN004.10 (~RESET), D003.1 (K), D003.10; also elsewhere on the board
/3-mcu-core/SDCARD_V_{DD}: CONN002.4 (VDD), R016.2, R017.2; also elsewhere on the board
/3-mcu-core/~CD: CONN002.10 (CD), D007.4 (K), D007.7; also elsewhere on the board
/3-mcu-core/~SDCARD_BUSYLED: LED001.1 (K); also elsewhere on the board
/3-mcu-core/~WP: CONN002.9 (WP), D007.1 (K), D007.10; also elsewhere on the board
/4-audio-out/AUDIO_SPK+: SPK001.1; also elsewhere on the board
/4-audio-out/AUDIO_SPK-: SPK001.2; also elsewhere on the board
/6-tft-driver/TFT0.LED_{K}: CONN005.4 (LED_{K}); also elsewhere on the board
/6-tft-driver/TFT0.L_{IO1}: CONN005.15 (L_{IO1}); also elsewhere on the board
/6-tft-driver/TFT0.L_{IO2}: CONN005.17 (L_{IO2}); also elsewhere on the board
/6-tft-driver/TFT0.L_{IO3}: CONN005.19 (L_{IO3}); also elsewhere on the board
/6-tft-driver/TFT0.L_{SCLK}: CONN005.21 (L_{SCLK}); also elsewhere on the board
/6-tft-driver/TFT0.L_{SDIN}: CONN005.23 (L_{SDIN}); also elsewhere on the board
/6-tft-driver/TFT0.L_{TE}: CONN005.13 (L_{TE}); also elsewhere on the board
/6-tft-driver/TFT0.TP_{INT}: CONN005.9 (TP_INT); also elsewhere on the board
/6-tft-driver/TFT0.TP_{SCL}: CONN005.11 (TP_SCL); also elsewhere on the board
/6-tft-driver/TFT0.TP_{SDA}: CONN005.10 (TP_SDA); also elsewhere on the board
/6-tft-driver/TFT0.~L_{CS}: CONN005.16 (~L_{CS}); also elsewhere on the board
/6-tft-driver/TFT0.~L_{RES}: CONN005.1 (~L_{RES}); also elsewhere on the board
/6-tft-driver/TFT0.~TP_{RST}: CONN005.8 (~TP_RST); also elsewhere on the board
/6-tft-driver/TFT1.LED_{K}: CONN006.4 (LED_{K}); also elsewhere on the board
/6-tft-driver/TFT1.L_{IO1}: CONN006.15 (L_{IO1}); also elsewhere on the board
/6-tft-driver/TFT1.L_{IO2}: CONN006.17 (L_{IO2}); also elsewhere on the board
/6-tft-driver/TFT1.L_{IO3}: CONN006.19 (L_{IO3}); also elsewhere on the board
/6-tft-driver/TFT1.L_{SCLK}: CONN006.21 (L_{SCLK}); also elsewhere on the board
/6-tft-driver/TFT1.L_{SDIN}: CONN006.23 (L_{SDIN}); also elsewhere on the board
/6-tft-driver/TFT1.L_{TE}: CONN006.13 (L_{TE}); also elsewhere on the board
/6-tft-driver/TFT1.TP_{INT}: CONN006.9 (TP_INT); also elsewhere on the board
/6-tft-driver/TFT1.TP_{SCL}: CONN006.11 (TP_SCL); also elsewhere on the board
/6-tft-driver/TFT1.TP_{SDA}: CONN006.10 (TP_SDA); also elsewhere on the board
/6-tft-driver/TFT1.~L_{CS}: CONN006.16 (~L_{CS}); also elsewhere on the board
/6-tft-driver/TFT1.~L_{RES}: CONN006.1 (~L_{RES}); also elsewhere on the board
/6-tft-driver/TFT1.~TP_{RST}: CONN006.8 (~TP_RST); also elsewhere on the board
/BC805M_V_{DD}: C001.1, C002.1, C003.1, D001.5 (K), D001.6, FB001.1 (P1_PWROUT), R001.2, R002.1, R003.1, R012.1, U001.9 (VDD)
/CORE_VDD_{+3.3V}: C004.1, C005.1, C006.1, C007.1, C008.1, C009.1, C010.1, CONN005.3 (V_{DDIO}), CONN005.6 (V_{DD}), CONN005.12 (TP_V_{DD}), CONN006.3 (V_{DDIO}), CONN006.6 (V_{DD}), CONN006.12 (TP_V_{DD}), FB001.2 (P2_PWRIN), R015.2, U002.2 (V_{DD}); also elsewhere on the board
/~BC805M_RESET: CONN003.10 (~RESET), D001.4 (K), D001.7, R013.1, R014.1, U001.4 (~RESET)
unnamed: C011.1, R012.2, R013.2
unnamed: CONN002.3 (CMD), R020.1
unnamed: CONN002.7 (DAT0), R019.1
unnamed: CONN002.8 (DAT1), R018.1
unnamed: CONN002.1 (DAT2), R022.1
unnamed: CONN002.2 (DAT3/CD), R021.1
unnamed: CONN003.4 (SWDCLK), D001.2 (K), D001.9, R005.1, R006.1
unnamed: CONN003.2 (SWDIO), D001.1 (K), D001.10, R003.2, R004.1
unnamed: CONN003.6 (SWO), R002.2
unnamed: CONN003.1 (V_{CC}), R001.1
unnamed: CONN004.1 (V_{CC}), R015.1
unnamed: LED001.2 (A), R016.1, R017.1
unnamed: R010.2, U001.7 (P012)
unnamed: R011.1, U001.11 (P014)
unnamed: R009.2, U001.6 (P016)
unnamed: R008.2, U001.5 (P018)
unnamed: R007.2, U001.3 (P020)

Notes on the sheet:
D006A-D
D002D,C,A,B
D001A-C
D005B
TODO: CHECK DATASHEETS AFTER COMPLETED THE LAYOUT - REMOVE ANY FOR PARTS THAT ARE NOT USED (PERHAPS MMBT3904 ?) AND ADD ANY THAT ARE MISSING.
UART pins named from the MCU perspective
The speaker should have a resonant frequency of less than 600Hz to cater for the lower-frequency bird sounds, such as the song of the tawny owl which has components around the 700Hz range. The speaker is connected to the PCB via a 2-pin header and pigtails. It is housed inside the clock's base / st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
D003C,A
Unless otherwise specified: All resistors and capacitors are 0402 All resistors are ±1% 100ppm 0.625W thick-film All capacitors are ±20% X5R 10V MLCC
D003B,D
D004D,B
D007B,D,A,C
R016-17
TODO: FOOTPRINTS FOR THE EYES - NO SYMBOL REQUIRED, HOWEVER.
R018-022
R004-5
D05A D004A,C
R007-10
D005C,D

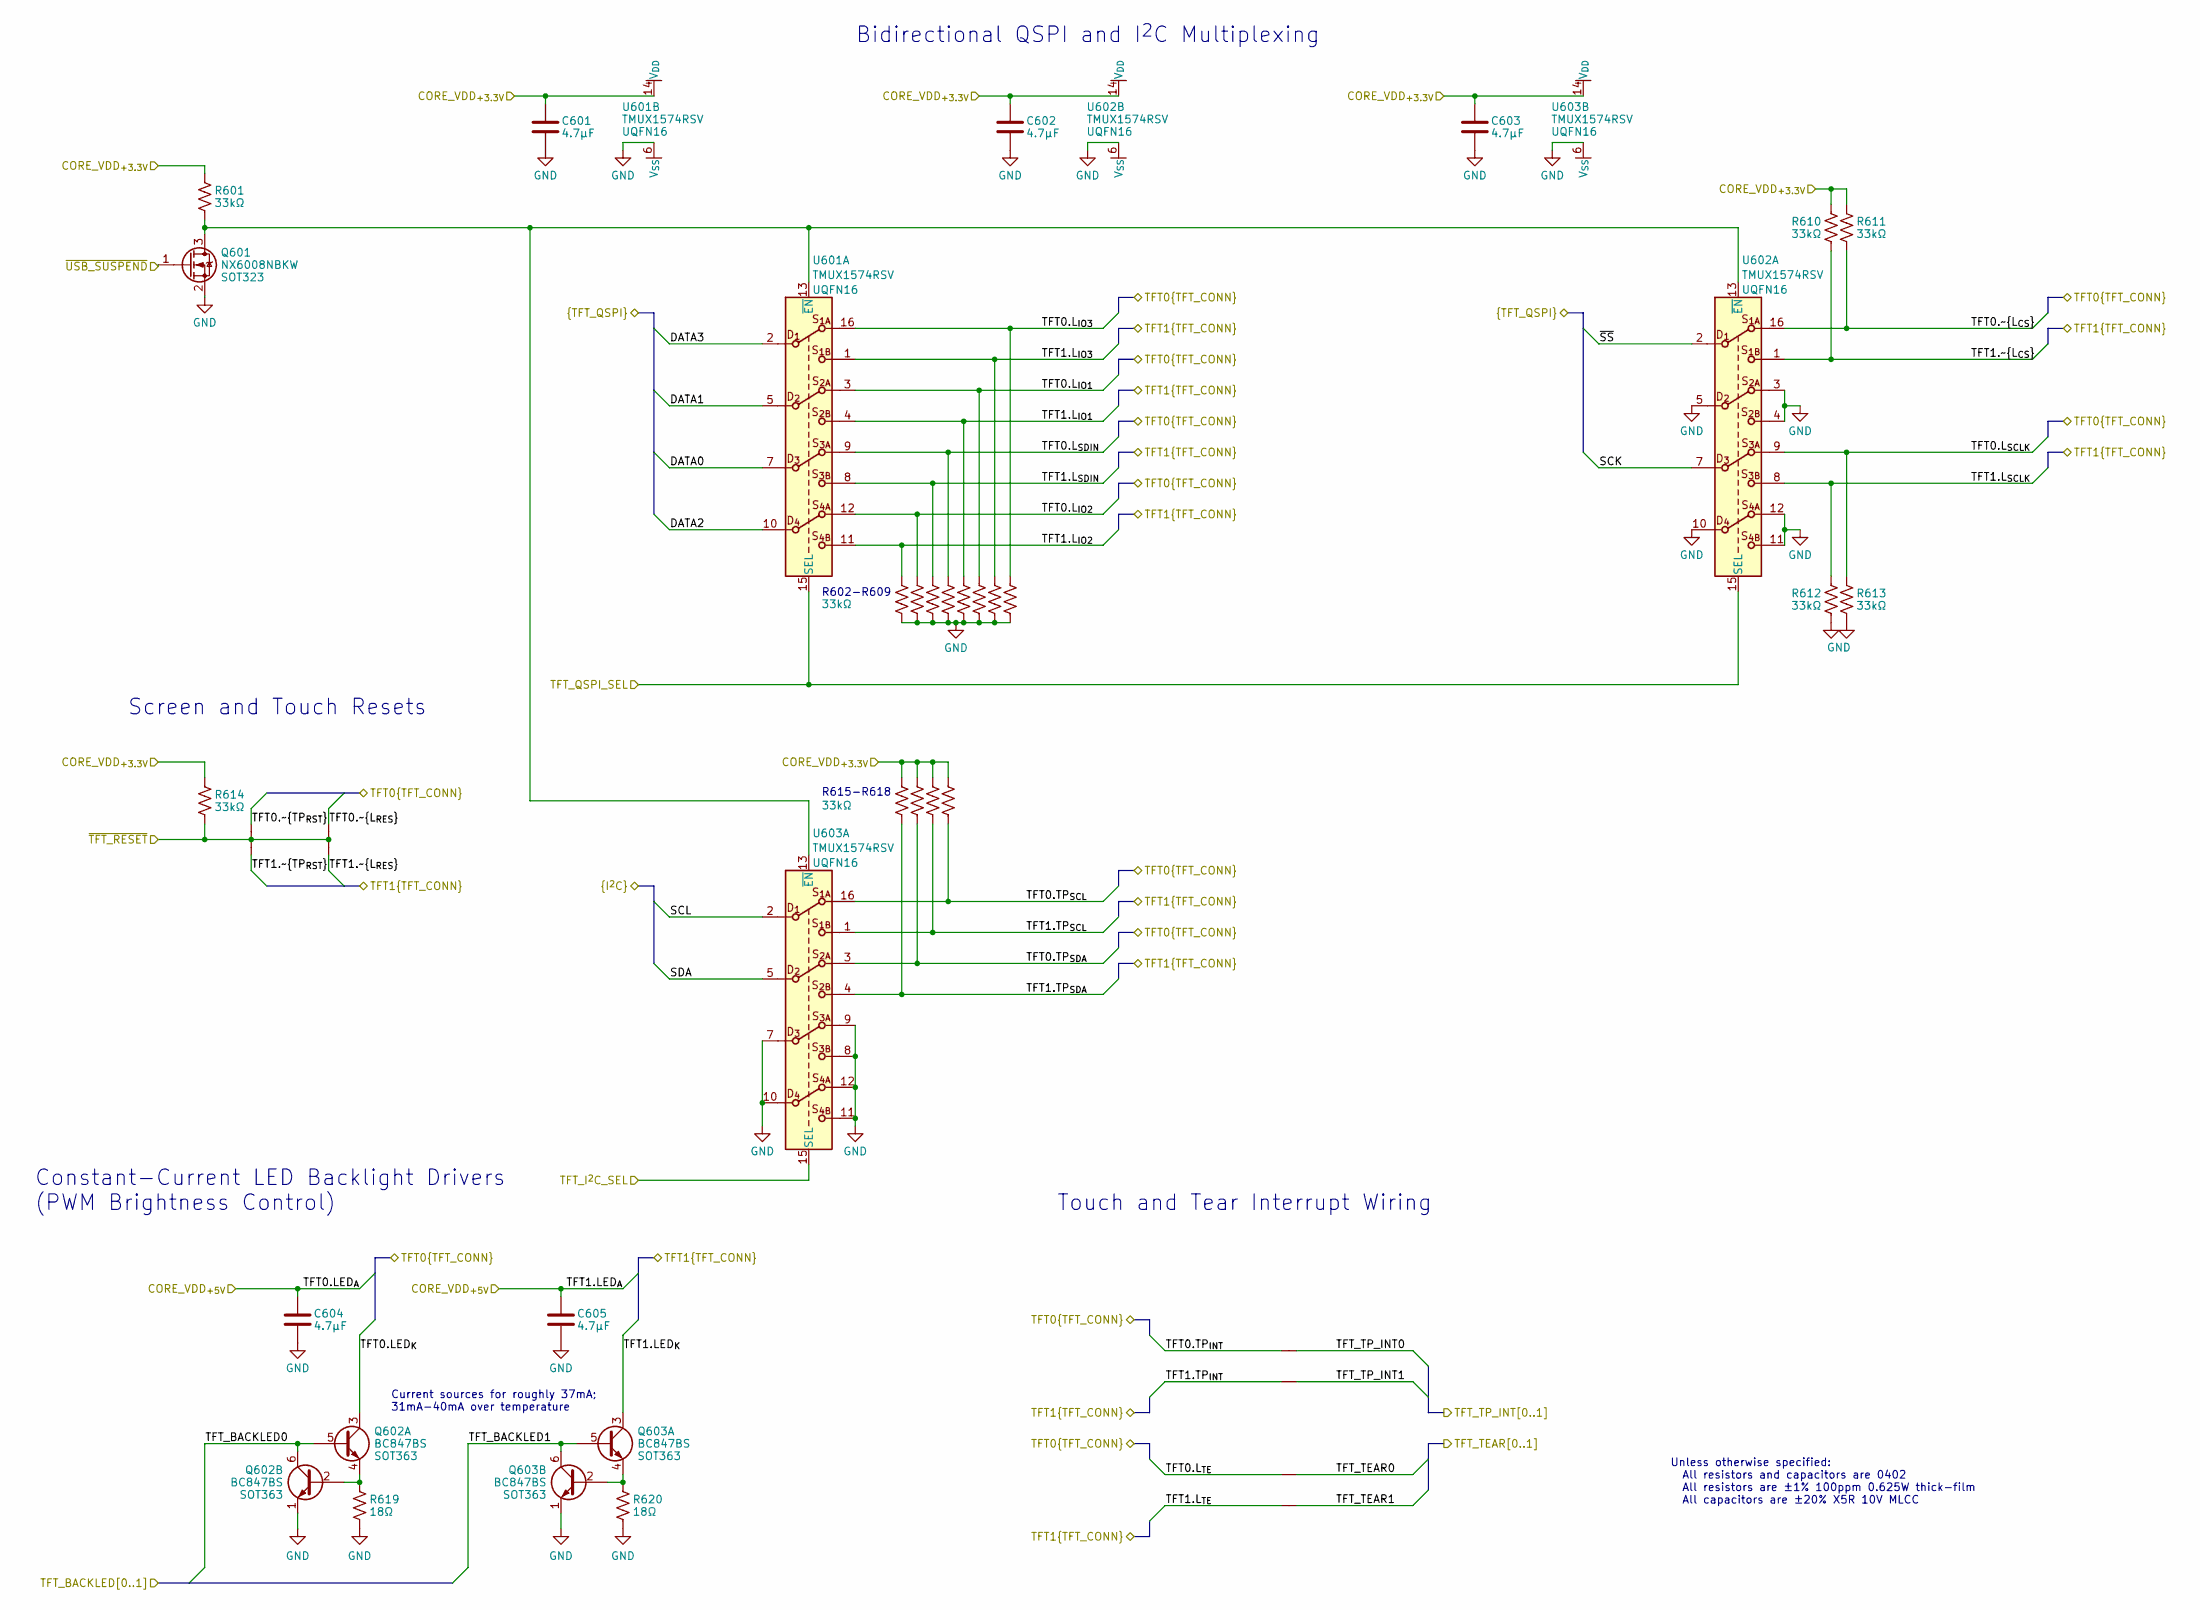
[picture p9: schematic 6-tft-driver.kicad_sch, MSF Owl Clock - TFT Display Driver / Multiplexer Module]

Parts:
C601, C602, C603, C604, C605: 4.7μF; unpolarised-nominal-0402-1005; Tolerance ±20%; VoltageRating 10V; ManufacturerPartNumber CL05A475MP5NRNC
NT601, NT602, NT603, NT604, NT605, NT606, NT607, NT608: Net Tie; net-tie-2-6mil
Q601: NX6008NBKW; SOT323; ManufacturerPartNumber NX6008NBKW
Q602, Q603: BC847BS; SOT363; ManufacturerPartNumber BC847BS-7-F
R601, R602, R603, R604, R605, R606, R607, R608, R609, R610, R611, R612, R613, R614, R615, R616, R617, R618: 33kΩ; nominal-0402-1005; Tolerance ±1%; ManufacturerPartNumber WR04X3302FTL
R619, R620: 18Ω; nominal-0402-1005; Tolerance ±1%; ManufacturerPartNumber RC0402FR-0718RL
U601, U602, U603: TMUX1574RSV; UQFN16-1.8x2.6mm-0.4mm; ManufacturerPartNumber TMUX1574RSVR

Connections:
/1-usb-and-power/CORE_VDD_{+5V}: C604.1, C605.1; also elsewhere on the board
/1-usb-and-power/SCL: U603.2; also elsewhere on the board
/1-usb-and-power/SDA: U603.5; also elsewhere on the board
/1-usb-and-power/~USB_SUSPEND: Q601.1 (G); also elsewhere on the board
/3-mcu-core/DATA0: U601.7; also elsewhere on the board
/3-mcu-core/DATA1: U601.5; also elsewhere on the board
/3-mcu-core/DATA2: U601.10; also elsewhere on the board
/3-mcu-core/DATA3: U601.2; also elsewhere on the board
/3-mcu-core/SCK: U602.7; also elsewhere on the board
/3-mcu-core/TFT_BACKLED0: Q602.5 (B), Q602.6 (C); also elsewhere on the board
/3-mcu-core/TFT_BACKLED1: Q603.5 (B), Q603.6 (C); also elsewhere on the board
/3-mcu-core/TFT_I^{2}C_SEL: U603.15 (SEL); also elsewhere on the board
/3-mcu-core/TFT_QSPI_SEL: U601.15 (SEL), U602.15 (SEL); also elsewhere on the board
/3-mcu-core/TFT_TEAR0: NT603.2 (P2_OUT); also elsewhere on the board
/3-mcu-core/TFT_TEAR1: NT604.2 (P2_OUT); also elsewhere on the board
/3-mcu-core/TFT_TP_INT0: NT601.2 (P2_OUT); also elsewhere on the board
/3-mcu-core/TFT_TP_INT1: NT602.2 (P2_OUT); also elsewhere on the board
/3-mcu-core/~SS: U602.2; also elsewhere on the board
/3-mcu-core/~TFT_RESET: NT605.1 (P1_IN), NT606.1 (P1_IN), NT607.1 (P1_IN), NT608.1 (P1_IN), R614.2; also elsewhere on the board
/6-tft-driver/TFT0.LED_{K}: Q602.3 (C); also elsewhere on the board
/6-tft-driver/TFT0.L_{IO1}: R607.1, U601.3; also elsewhere on the board
/6-tft-driver/TFT0.L_{IO2}: R603.1, U601.12; also elsewhere on the board
/6-tft-driver/TFT0.L_{IO3}: R609.1, U601.16; also elsewhere on the board
/6-tft-driver/TFT0.L_{SCLK}: R613.1, U602.9; also elsewhere on the board
/6-tft-driver/TFT0.L_{SDIN}: R605.1, U601.9; also elsewhere on the board
/6-tft-driver/TFT0.L_{TE}: NT603.1 (P1_IN); also elsewhere on the board
/6-tft-driver/TFT0.TP_{INT}: NT601.1 (P1_IN); also elsewhere on the board
/6-tft-driver/TFT0.TP_{SCL}: R618.2, U603.16; also elsewhere on the board
/6-tft-driver/TFT0.TP_{SDA}: R616.2, U603.3; also elsewhere on the board
/6-tft-driver/TFT0.~L_{CS}: R611.2, U602.16; also elsewhere on the board
/6-tft-driver/TFT0.~L_{RES}: NT607.2 (P2_OUT); also elsewhere on the board
/6-tft-driver/TFT0.~TP_{RST}: NT605.2 (P2_OUT); also elsewhere on the board
/6-tft-driver/TFT1.LED_{K}: Q603.3 (C); also elsewhere on the board
/6-tft-driver/TFT1.L_{IO1}: R606.1, U601.4; also elsewhere on the board
/6-tft-driver/TFT1.L_{IO2}: R602.1, U601.11; also elsewhere on the board
/6-tft-driver/TFT1.L_{IO3}: R608.1, U601.1; also elsewhere on the board
/6-tft-driver/TFT1.L_{SCLK}: R612.1, U602.8; also elsewhere on the board
/6-tft-driver/TFT1.L_{SDIN}: R604.1, U601.8; also elsewhere on the board
/6-tft-driver/TFT1.L_{TE}: NT604.1 (P1_IN); also elsewhere on the board
/6-tft-driver/TFT1.TP_{INT}: NT602.1 (P1_IN); also elsewhere on the board
/6-tft-driver/TFT1.TP_{SCL}: R617.2, U603.1; also elsewhere on the board
/6-tft-driver/TFT1.TP_{SDA}: R615.2, U603.4; also elsewhere on the board
/6-tft-driver/TFT1.~L_{CS}: R610.2, U602.1; also elsewhere on the board
/6-tft-driver/TFT1.~L_{RES}: NT608.2 (P2_OUT); also elsewhere on the board
/6-tft-driver/TFT1.~TP_{RST}: NT606.2 (P2_OUT); also elsewhere on the board
/CORE_VDD_{+3.3V}: C601.1, C602.1, C603.1, R601.1, R610.1, R611.1, R614.1, R615.1, R616.1, R617.1, R618.1, U601.14 (V_{DD}), U602.14 (V_{DD}), U603.14 (V_{DD}); also elsewhere on the board
unnamed: Q601.3 (D), R601.2, U601.13 (~EN), U602.13 (~EN), U603.13 (~EN)
unnamed: Q602.2 (B), Q602.4 (E), R619.1
unnamed: Q603.2 (B), Q603.4 (E), R620.1

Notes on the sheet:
Screen and Touch Resets
R615-R618
R602-R609
Constant-Current LED Backlight Drivers (PWM Brightness Control)
Current sources for roughly 37mA; 31mA-40mA over temperature
Bidirectional QSPI and I^{2}C Multiplexing
Touch and Tear Interrupt Wiring
Unless otherwise specified: All resistors and capacitors are 0402 All resistors are ±1% 100ppm 0.625W thick-film All capacitors are ±20% X5R 10V MLCC

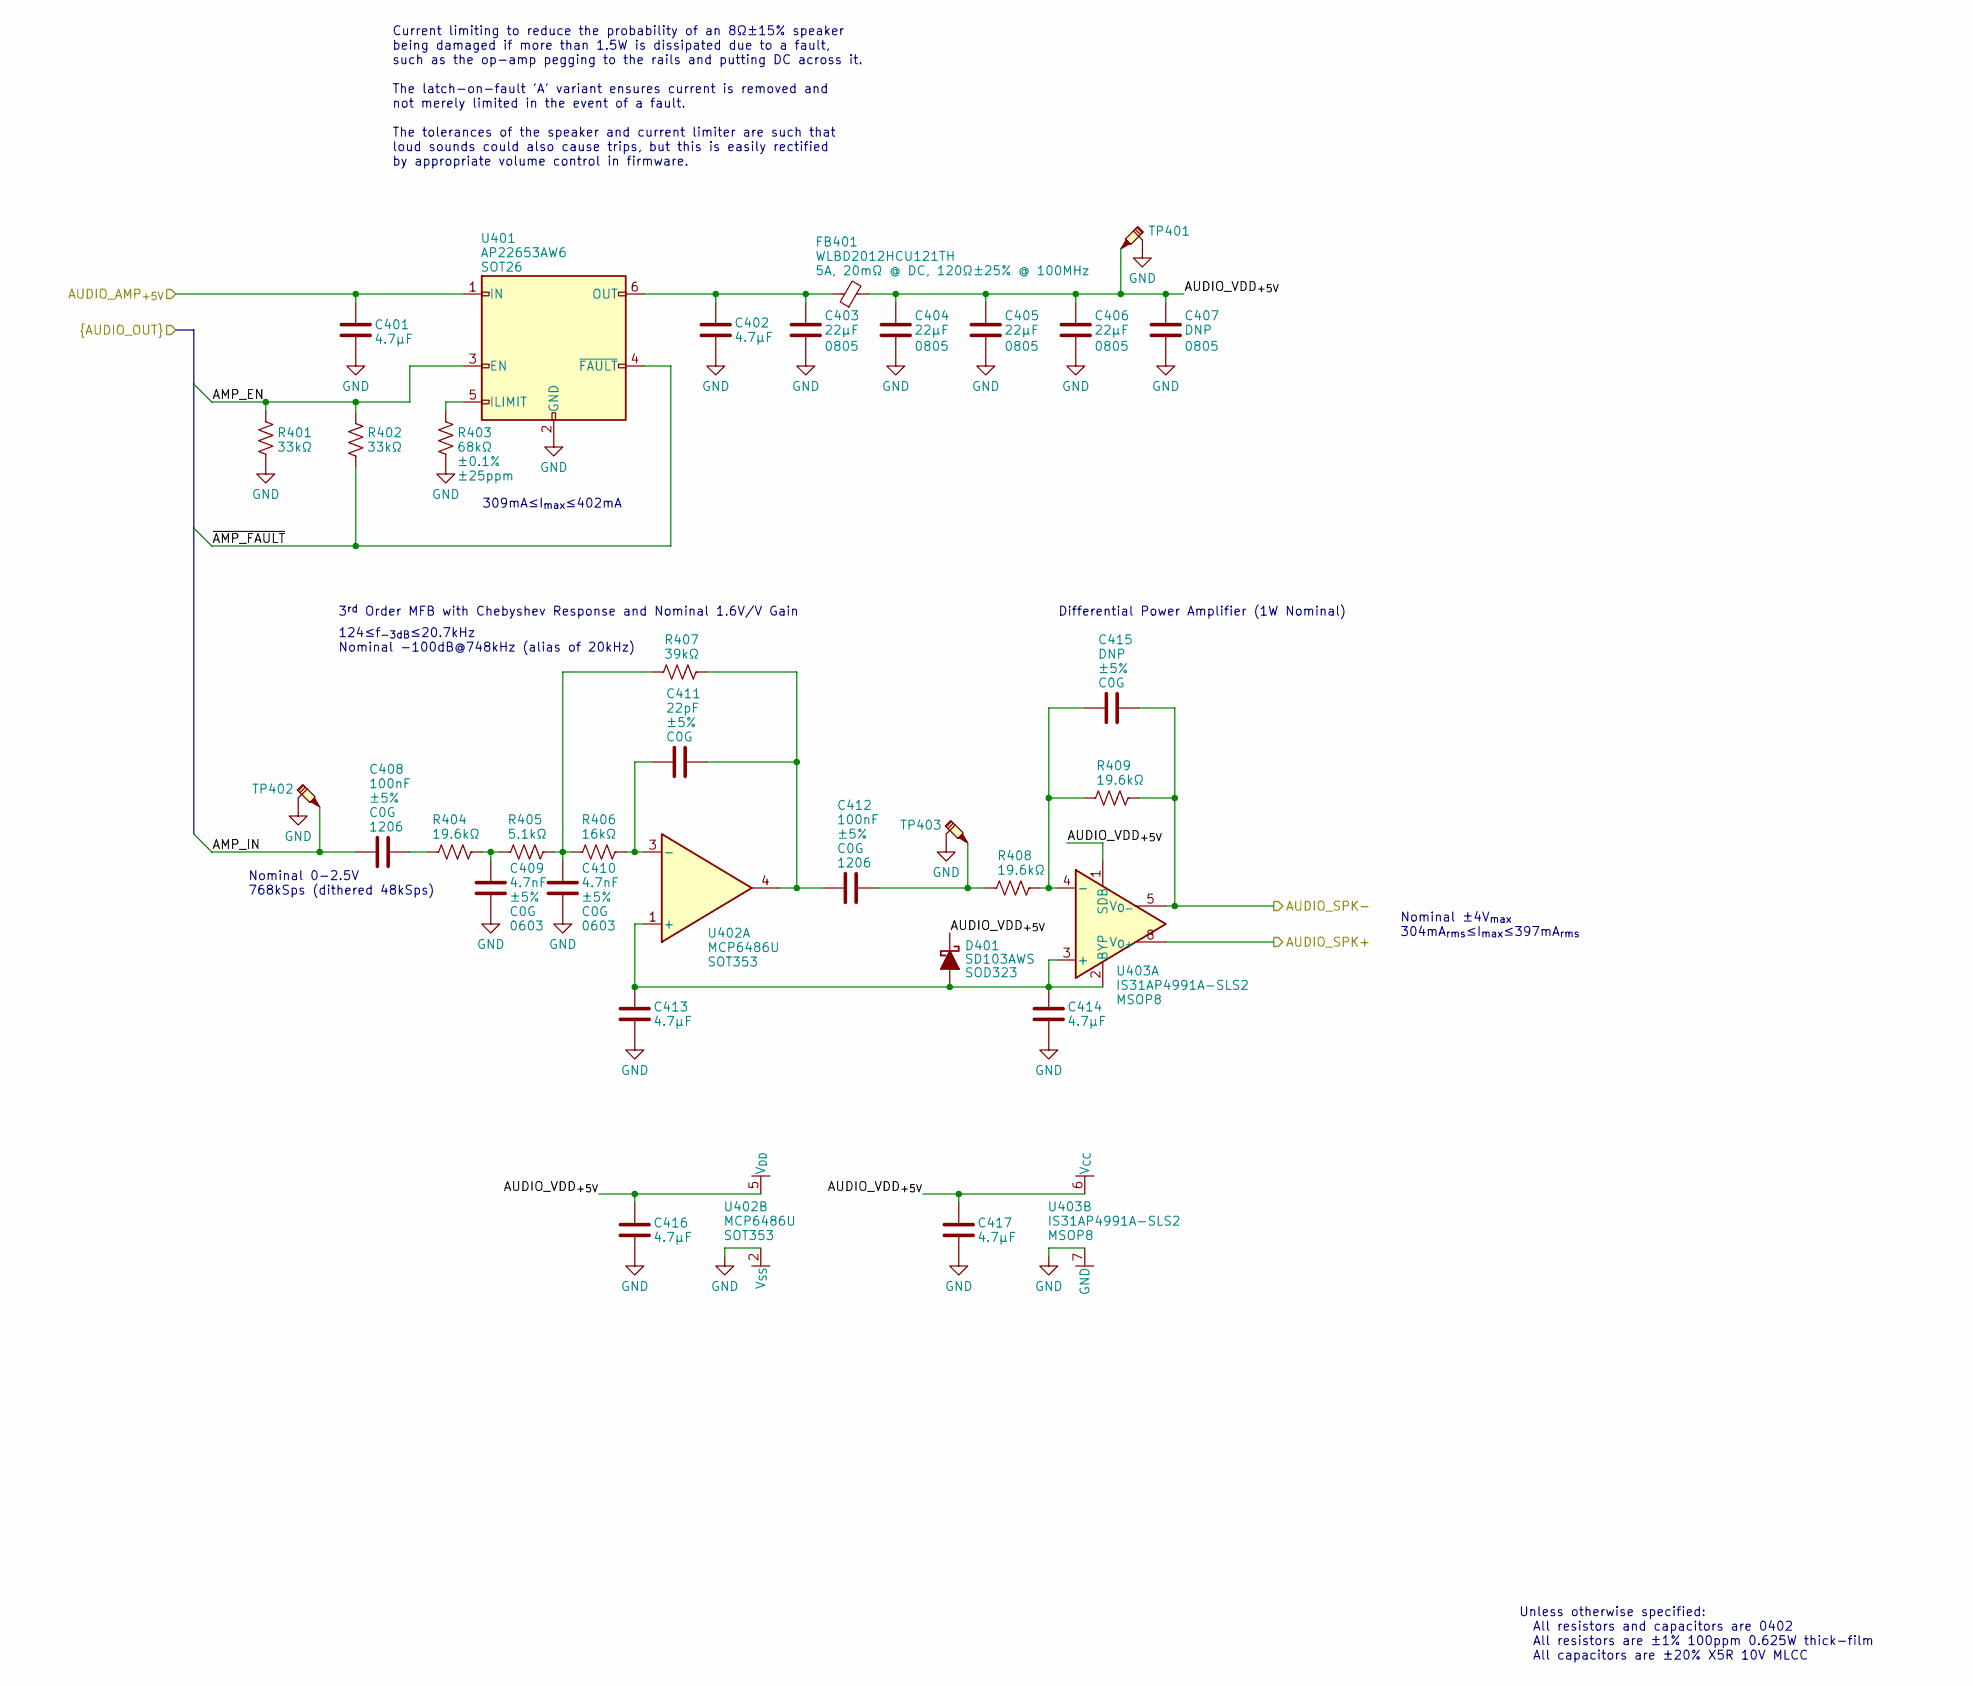
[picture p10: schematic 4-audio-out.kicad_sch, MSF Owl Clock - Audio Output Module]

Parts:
C401, C402, C413, C414, C416, C417: 4.7μF; unpolarised-nominal-0402-1005; Tolerance ±20%; VoltageRating 10V; ManufacturerPartNumber CL05A475MP5NRNC
C403, C404, C405, C406: 22μF; unpolarised-nominal-0805-2012; Tolerance ±20%; VoltageRating 10V; ManufacturerPartNumber CL21A226MPQNNN
C407: DNP; unpolarised-nominal-0805-2012; Tolerance ±20%; VoltageRating 10V; ManufacturerPartNumber CL21A226MPQNNN
C408, C412: 100nF; unpolarised-nominal-1206-3216; Tolerance ±5%; VoltageRating 10V; ManufacturerPartNumber GRM3195C1H104JA05D
C409, C410: 4.7nF; unpolarised-nominal-0603-1608; Tolerance ±5%; VoltageRating 10V; ManufacturerPartNumber CC0603FRNPO9BN472
C411: 22pF; unpolarised-nominal-0402-1005; Tolerance ±5%; VoltageRating 10V; ManufacturerPartNumber GCM1555C1H220FA16D
C415: DNP; unpolarised-nominal-0402-1005; Tolerance ±5%; VoltageRating 10V
D401: SD103AWS; SOD323; ManufacturerPartNumber SD103AWS
FB401: WLBD2012HCU121TH; WLBD2012; Tolerance ±25%; ManufacturerPartNumber WLBD2012HCU121TH
R401, R402: 33kΩ; nominal-0402-1005; Tolerance ±1%; ManufacturerPartNumber WR04X3302FTL
R403: 68kΩ; nominal-0402-1005; Tolerance ±0.1%; ManufacturerPartNumber RN73R1ETTP6802B25
R404, R408, R409: 19.6kΩ; nominal-0402-1005; Tolerance ±1%; ManufacturerPartNumber WR04X1962FTL
R405: 5.1kΩ; nominal-0402-1005; Tolerance ±1%; ManufacturerPartNumber WR04X5101FTL
R406: 16kΩ; nominal-0402-1005; Tolerance ±1%; ManufacturerPartNumber AC0402DR-0716KL
R407: 39kΩ; nominal-0402-1005; Tolerance ±1%; ManufacturerPartNumber RC0402FR-0739KL
TP401, TP402, TP403: testpoint-SP3050A-with-short-gnd
U401: AP22653AW6; SOT26; ManufacturerPartNumber AP22653AW6-7
U402: MCP6486U; SOT353; ManufacturerPartNumber MCP6486UT-E-LT
U403: IS31AP4991A-SLS2; MSOP8-3x3mm-0.65mm; ManufacturerPartNumber IS31AP4991A-SLS2-TR

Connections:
/1-usb-and-power/CORE_VDD_{+5V}: C401.1, U401.1 (IN); also elsewhere on the board
/3-mcu-core/AMP_EN: R401.1, R402.1, U401.3 (EN); also elsewhere on the board
/3-mcu-core/AMP_IN: C408.1, TP402.1; also elsewhere on the board
/3-mcu-core/~AMP_FAULT: R402.2, U401.4 (~FAULT); also elsewhere on the board
/4-audio-out/AUDIO_SPK+: U403.8 (V_{O+}); also elsewhere on the board
/4-audio-out/AUDIO_SPK-: C415.2, R409.2, U403.5 (V_{O-}); also elsewhere on the board
/4-audio-out/AUDIO_VDD_{+5V}: C404.1, C405.1, C406.1, C407.1, C416.1, C417.1, D401.1 (K), FB401.2 (P2_PWROUT), TP401.1, U402.5 (V_{DD}), U403.1 (SDB), U403.6 (V_{CC})
unnamed: C408.2, R404.1
unnamed: C409.2, R404.2, R405.1
unnamed: C410.2, R405.2, R406.1, R407.1
unnamed: C411.2, C412.1, R407.2, U402.4
unnamed: C412.2, R408.1, TP403.1
unnamed: C413.1, C414.1, D401.2 (A), U402.1 (+), U403.2 (BYP), U403.3 (+)
unnamed: C402.1, C403.1, FB401.1 (P1_PWRIN), U401.6 (OUT)
unnamed: R403.1, U401.5 (ILIMIT)
unnamed: C411.1, R406.2, U402.3 (-)
unnamed: C415.1, R408.2, R409.1, U403.4 (-)

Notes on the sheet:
Differential Power Amplifier (1W Nominal)
3^{rd} Order MFB with Chebyshev Response and Nominal 1.6V/V Gain
Nominal ±4V_{max} 304mA_{rms}≤I_{max}≤397mA_{rms}
Current limiting to reduce the probability of an 8Ω±15% speaker being damaged if more than 1.5W is dissipated due to a fault, such as the op-amp pegging to the rails and putting DC across it. The latch-on-fault 'A' variant ensures current is removed and not merely limited in the event of a fault. T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
124≤f_{-3dB}≤20.7kHz Nominal -100dB@748kHz (alias of 20kHz)
Nominal 0-2.5V 768kSps (dithered 48kSps)
Unless otherwise specified: All resistors and capacitors are 0402 All resistors are ±1% 100ppm 0.625W thick-film All capacitors are ±20% X5R 10V MLCC
309mA≤I_{max}≤402mA

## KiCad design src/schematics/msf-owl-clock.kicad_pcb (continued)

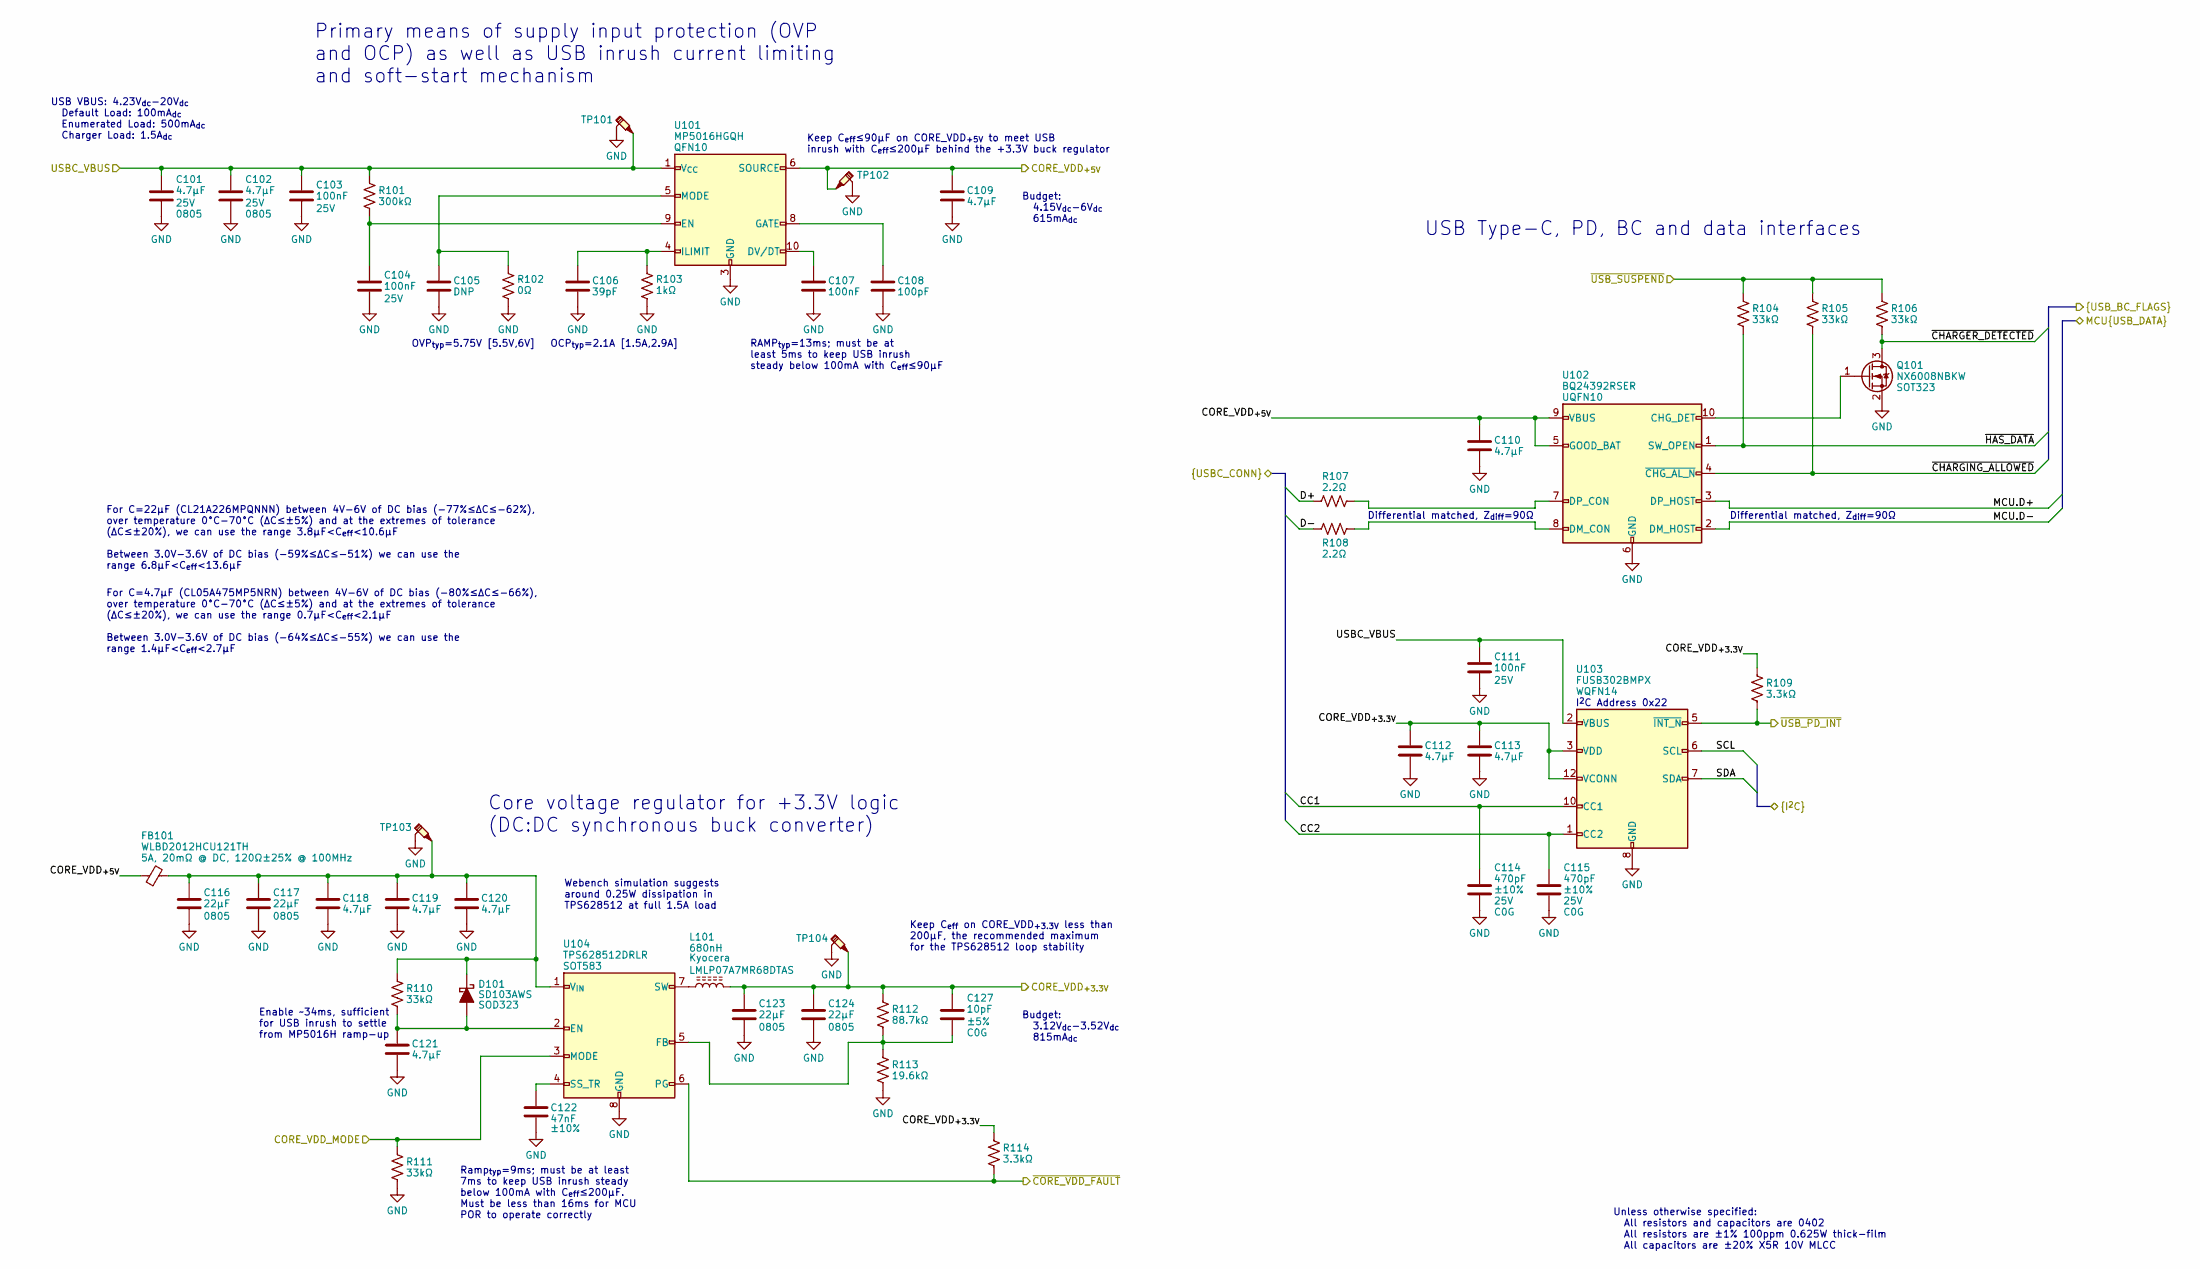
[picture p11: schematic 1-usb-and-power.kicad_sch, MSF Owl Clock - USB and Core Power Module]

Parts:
C101, C102: 4.7μF; unpolarised-nominal-0805-2012; Tolerance ±10%; VoltageRating 25V; ManufacturerPartNumber CL21A475KAQNNNE
C103, C104, C111: 100nF; unpolarised-nominal-0402-1005; Tolerance ±20%; VoltageRating 25V; ManufacturerPartNumber CL05B104KA5NNNC
C105: DNP; unpolarised-nominal-0402-1005; Tolerance ±10%; VoltageRating 10V
C106: 39pF; unpolarised-nominal-0402-1005; Tolerance ±10%; VoltageRating 10V; ManufacturerPartNumber CC0402JRNPO9BN390
C107: 100nF; unpolarised-nominal-0402-1005; Tolerance ±20%; VoltageRating 10V; ManufacturerPartNumber CL05B104KA5NNNC
C108: 100pF; unpolarised-nominal-0402-1005; Tolerance ±10%; VoltageRating 10V; ManufacturerPartNumber GMC04CG101G50NT
C109, C110, C112, C113, C118, C119, C120, C121: 4.7μF; unpolarised-nominal-0402-1005; Tolerance ±20%; VoltageRating 10V; ManufacturerPartNumber CL05A475MP5NRNC
C114, C115: 470pF; unpolarised-nominal-0402-1005; Tolerance ±10%; VoltageRating 25V; ManufacturerPartNumber GCM1555C1H471FA16D
C116, C117, C123, C124: 22μF; unpolarised-nominal-0805-2012; Tolerance ±20%; VoltageRating 10V; ManufacturerPartNumber CL21A226MPQNNN
C122: 47nF; unpolarised-nominal-0402-1005; Tolerance ±10%; VoltageRating 10V; ManufacturerPartNumber VJ0402Y473KXQCW1BC
C127: 10pF; unpolarised-nominal-0402-1005; Tolerance ±5%; VoltageRating 10V; ManufacturerPartNumber 885012005007
D101: SD103AWS; SOD323; ManufacturerPartNumber SD103AWS
FB101: WLBD2012HCU121TH; WLBD2012; Tolerance ±25%; ManufacturerPartNumber WLBD2012HCU121TH
L101: 680nH; 07A7; Tolerance ±20%; ManufacturerPartNumber LMLP07A7MR68DTAS
Q101: NX6008NBKW; SOT323; ManufacturerPartNumber NX6008NBKW
R101: 300kΩ; nominal-0402-1005; Tolerance ±1%; ManufacturerPartNumber RC0402FR-07300KL
R102: 0Ω; nominal-0402-1005; Tolerance ±1%; ManufacturerPartNumber RC0402FR-070RL
R103: 1kΩ; nominal-0402-1005; Tolerance ±1%; ManufacturerPartNumber WR04X1001FTL
R104, R105, R106, R110, R111: 33kΩ; nominal-0402-1005; Tolerance ±1%; ManufacturerPartNumber WR04X3302FTL
R107, R108: 2.2Ω; nominal-0402-1005; Tolerance ±1%; ManufacturerPartNumber RMCF0402FT2R20
R109, R114: 3.3kΩ; nominal-0402-1005; Tolerance ±1%; ManufacturerPartNumber CRCW04022R20FKED
R112: 88.7kΩ; nominal-0402-1005; Tolerance ±1%; ManufacturerPartNumber WR04X8872FTL
R113: 19.6kΩ; nominal-0402-1005; Tolerance ±1%; ManufacturerPartNumber WR04X1962FTL
TP101, TP102, TP103, TP104: testpoint-SP3050A-with-short-gnd
U101: MP5016HGQH; QFN10-1.5x2.0mm-0.5mm; ManufacturerPartNumber MP5016HGQH
U102: BQ24392RSER; UQFN10-1.5x2.0mm-0.5mm; ManufacturerPartNumber BQ24392RSER
U103: FUSB302BMPX; WQFN14-2.5x2.5mm-0.5mm-expad-1.45x1.45mm-thermvias; ManufacturerPartNumber FUSB302BMPX
U104: TPS628512DRLR; SOT583; ManufacturerPartNumber TPS628512DRLR

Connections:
/1-usb-and-power/CC1: C114.1, U103.10 (CC1), U103.11 (CC1); also elsewhere on the board
/1-usb-and-power/CC2: C115.1, U103.1 (CC2), U103.14 (CC2); also elsewhere on the board
/1-usb-and-power/CORE_VDD_MODE: R111.1, U104.3 (MODE); also elsewhere on the board
/1-usb-and-power/CORE_VDD_{+5V}: C109.1, C110.1, FB101.1 (P1_PWRIN), TP102.1, U101.6 (SOURCE), U102.5 (GOOD_BAT), U102.9 (VBUS); also elsewhere on the board
/1-usb-and-power/D+: R107.1; also elsewhere on the board
/1-usb-and-power/D-: R108.1; also elsewhere on the board
/1-usb-and-power/MCU.D+: U102.3 (DP_HOST); also elsewhere on the board
/1-usb-and-power/MCU.D-: U102.2 (DM_HOST); also elsewhere on the board
/1-usb-and-power/SCL: U103.6 (SCL); also elsewhere on the board
/1-usb-and-power/SDA: U103.7 (SDA); also elsewhere on the board
/1-usb-and-power/USBC_VBUS: C101.1, C102.1, C103.1, C111.1, R101.1, TP101.1, U101.1 (V_{CC}), U103.2 (VBUS); also elsewhere on the board
/1-usb-and-power/~CHARGER_DETECTED: Q101.3 (D), R106.2; also elsewhere on the board
/1-usb-and-power/~CHARGING_ALLOWED: R105.2, U102.4 (~CHG_AL_N); also elsewhere on the board
/1-usb-and-power/~CORE_VDD_FAULT: R114.2, U104.6 (PG); also elsewhere on the board
/1-usb-and-power/~HAS_DATA: R104.2, U102.1 (SW_OPEN); also elsewhere on the board
/1-usb-and-power/~USB_PD_INT: R109.2, U103.5 (~INT_N); also elsewhere on the board
/1-usb-and-power/~USB_SUSPEND: R104.1, R105.1, R106.1; also elsewhere on the board
/CORE_VDD_{+3.3V}: C112.1, C113.1, C123.1, C124.1, C127.1, L101.2 (P2_PWROUT), R109.1, R112.1, R114.1, TP104.1, U103.3 (VDD), U103.4 (VDD), U103.12 (VCONN), U103.13 (VCONN); also elsewhere on the board
unnamed: C121.1, D101.2 (A), R110.2, U104.2 (EN)
unnamed: C116.1, C117.1, C118.1, C119.1, C120.1, D101.1 (K), FB101.2 (P2_PWROUT), R110.1, TP103.1, U104.1 (V_{IN})
unnamed: L101.1, U104.7 (SW)
unnamed: Q101.1 (G), U102.10 (CHG_DET)
unnamed: C107.1, U101.10 (DV/DT)
unnamed: C104.1, R101.2, U101.9 (EN)
unnamed: C108.1, U101.8 (GATE)
unnamed: C106.1, R103.1, U101.4 (ILIMIT)
unnamed: C105.1, R102.1, U101.5 (MODE)
unnamed: R108.2, U102.8 (DM_CON)
unnamed: R107.2, U102.7 (DP_CON)
unnamed: C127.2, R112.2, R113.1, U104.5 (FB)
unnamed: C122.1, U104.4 (SS_TR)

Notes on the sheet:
Unless otherwise specified: All resistors and capacitors are 0402 All resistors are ±1% 100ppm 0.625W thick-film All capacitors are ±20% X5R 10V MLCC
Ramp_{typ}=9ms; must be at least 7ms to keep USB inrush steady below 100mA with C_{eff}≤200μF. Must be less than 16ms for MCU POR to operate correctly
Webench simulation suggests around 0.25W dissipation in TPS628512 at full 1.5A load
I^{2}C Address 0x22
Keep C_{eff}≤90μF on CORE_VDD_{+5V} to meet USB inrush with C_{eff}≤200μF behind the +3.3V buck regulator
Differential matched, Z_{diff}=90Ω
Enable ~34ms, sufficient for USB inrush to settle from MP5016H ramp-up
Primary means of supply input protection (OVP and OCP) as well as USB inrush current limiting and soft-start mechanism
Budget: 4.15V_{dc}-6V_{dc} 615mA_{dc}
For C=22μF (CL21A226MPQNNN) between 4V-6V of DC bias (-77%≤ΔC≤-62%), over temperature 0°C-70°C (ΔC≤±5%) and at the extremes of tolerance (ΔC≤±20%), we can use the range 3.8μF<C_{eff}<10.6μF Between 3.0V-3.6V of DC bias (-59%≤ΔC≤-51%) we can use the range 6.8μF<C_{eff}<13.6μF
Budget: 3.12V_{dc}-3.52V_{dc} 815mA_{dc}
USB VBUS: 4.23V_{dc}-20V_{dc} Default Load: 100mA_{dc} Enumerated Load: 500mA_{dc} Charger Load: 1.5A_{dc}
RAMP_{typ}=13ms; must be at least 5ms to keep USB inrush steady below 100mA with C_{eff}≤90μF
OCP_{typ}=2.1A [1.5A,2.9A]
Core voltage regulator for +3.3V logic (DC:DC synchronous buck converter)
For C=4.7μF (CL05A475MP5NRN) between 4V-6V of DC bias (-80%≤ΔC≤-66%), over temperature 0°C-70°C (ΔC≤±5%) and at the extremes of tolerance (ΔC≤±20%), we can use the range 0.7μF<C_{eff}<2.1μF Between 3.0V-3.6V of DC bias (-64%≤ΔC≤-55%) we can use the range 1.4μF<C_{eff}<2.7μF
OVP_{typ}=5.75V [5.5V,6V]
Keep C_{eff} on CORE_VDD_{+3.3V} less than 200μF, the recommended maximum for the TPS628512 loop stability
USB Type-C, PD, BC and data interfaces

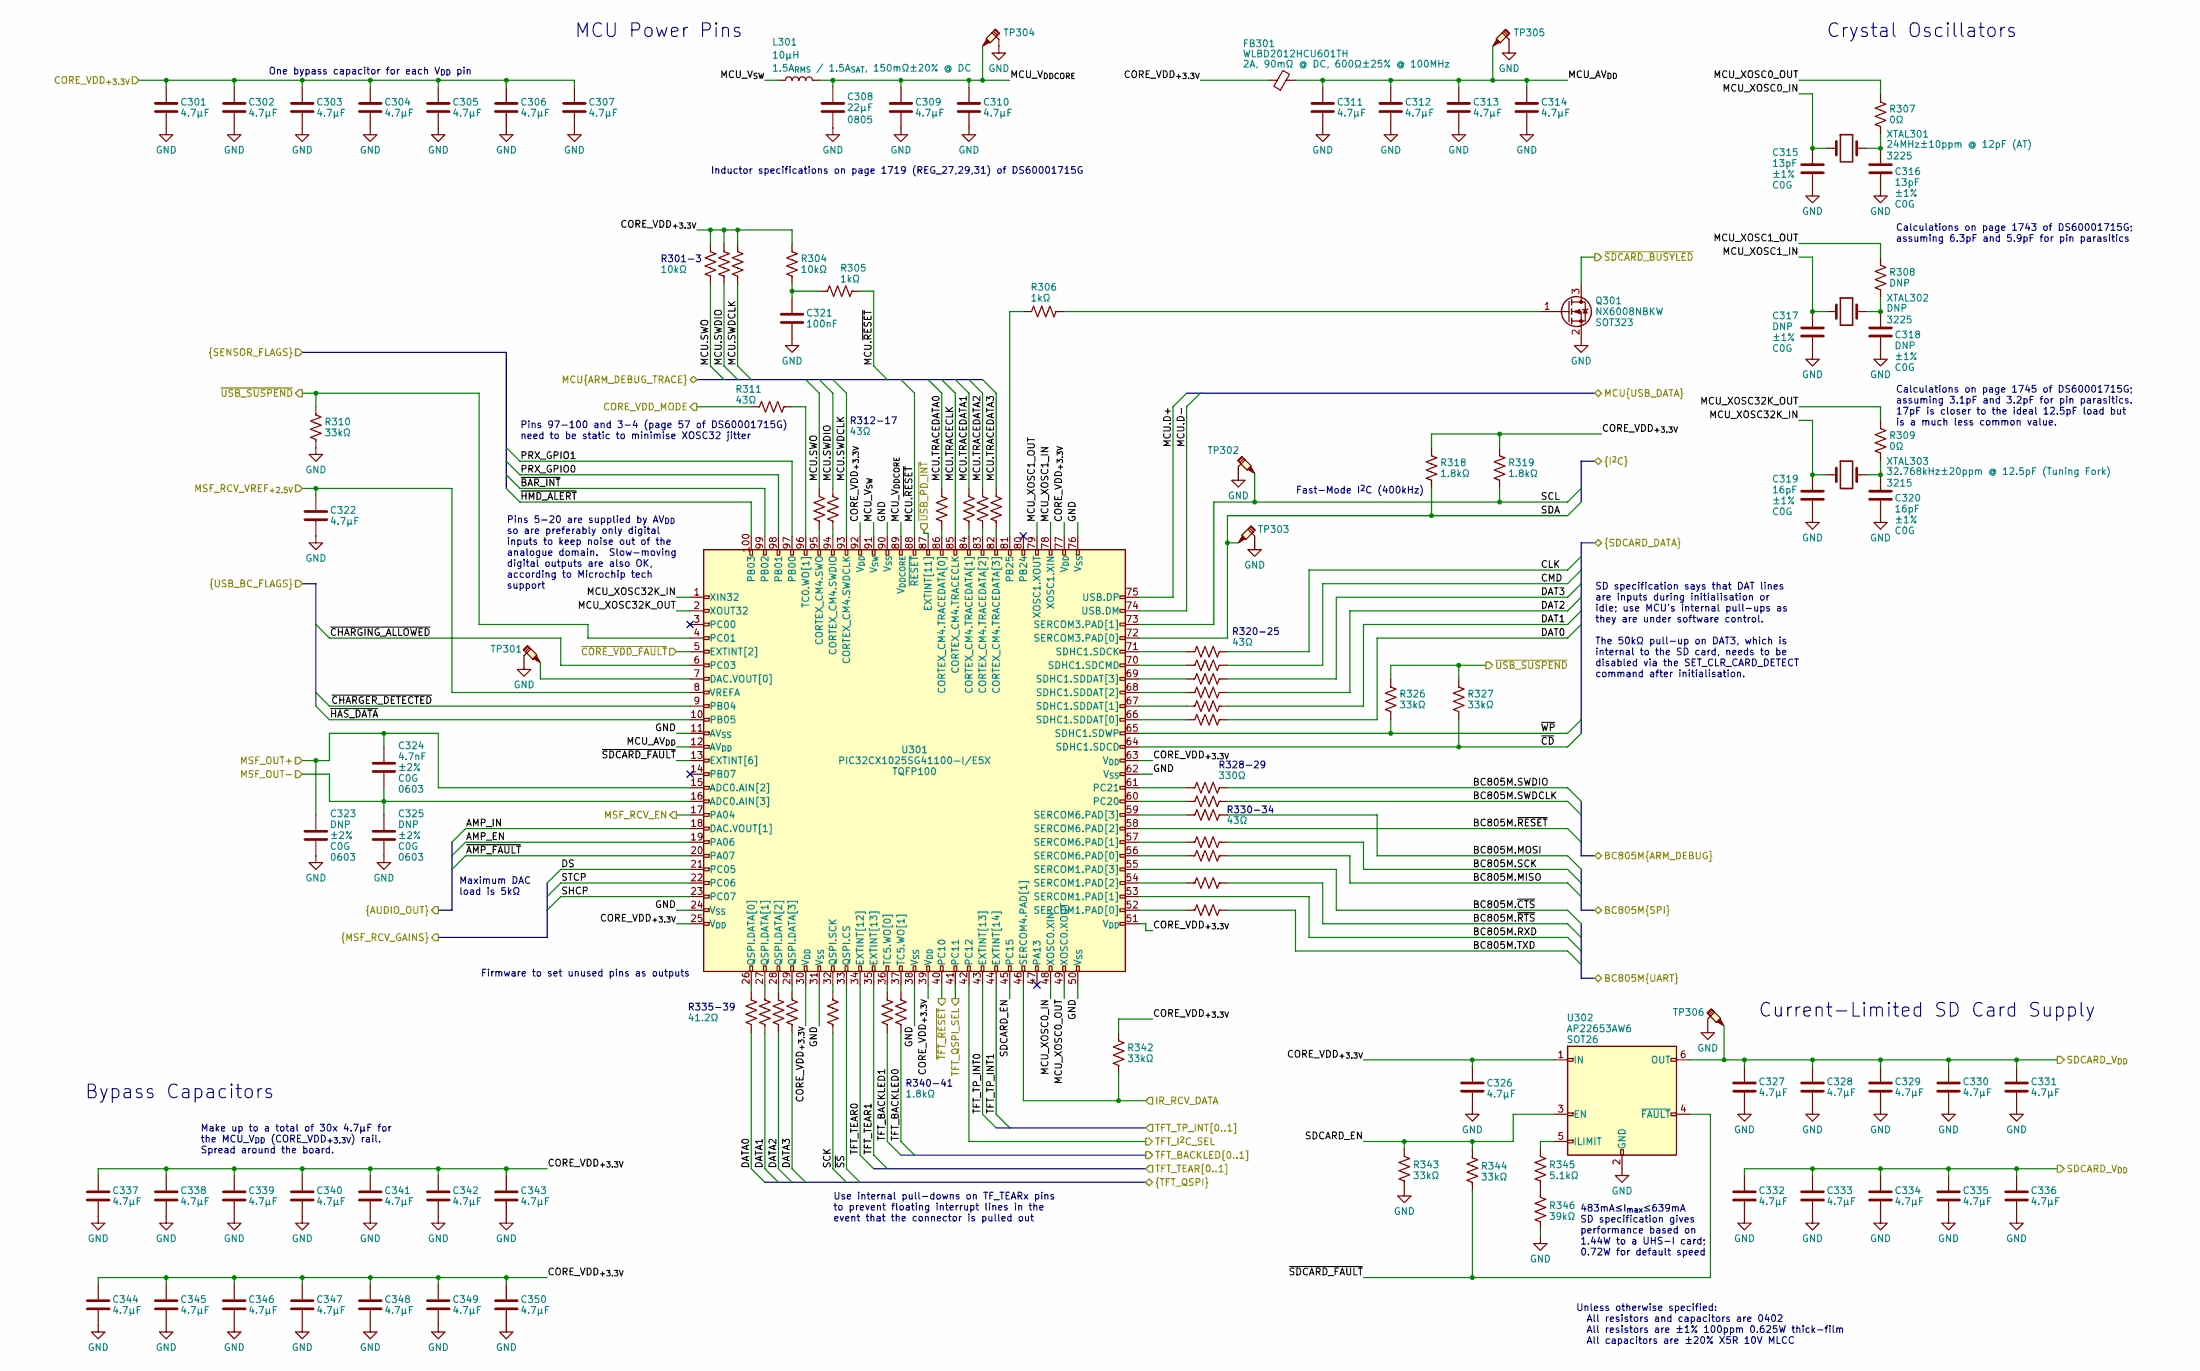
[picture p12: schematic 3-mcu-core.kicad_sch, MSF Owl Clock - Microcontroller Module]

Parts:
C301, C302, C303, C304, C305, C306, C307, C309, C310, C311, C312, C313, C314, C322, C326, C327, C328, C329, C330, C331, C332, C333, C334, C335, C336, C337, C338, C339, C340, C341, C342, C343, C344, C345, C346, C347, C348, C349, C350: 4.7μF; unpolarised-nominal-0402-1005; Tolerance ±20%; VoltageRating 10V; ManufacturerPartNumber CL05A475MP5NRNC
C308: 22μF; unpolarised-nominal-0805-2012; Tolerance ±20%; VoltageRating 10V; ManufacturerPartNumber CL21A226MPQNNN
C315, C316: 13pF; unpolarised-nominal-0402-1005; Tolerance ±1%; VoltageRating 10V; ManufacturerPartNumber GJM1555C1H130FB01D
C317, C318: DNP; unpolarised-nominal-0402-1005; Tolerance ±1%; VoltageRating 10V
C319, C320: 16pF; unpolarised-nominal-0402-1005; Tolerance ±1%; VoltageRating 10V; ManufacturerPartNumber GCM1555C1H160FA16D
C321: 100nF; unpolarised-nominal-0402-1005; Tolerance ±20%; VoltageRating 10V; ManufacturerPartNumber CL05B104KA5NNNC
C323, C325: DNP; unpolarised-nominal-0603-1608; Tolerance ±2%; VoltageRating 10V
C324: 4.7nF; unpolarised-nominal-0603-1608; Tolerance ±2%; VoltageRating 10V; ManufacturerPartNumber CC0603FRNPO9BN472
FB301: WLBD2012HCU601TH; WLBD2012; Tolerance ±25%; ManufacturerPartNumber WLBD2012HCU601TH
L301: 10μH; HPC4018NF; Tolerance ±20%; ManufacturerPartNumber HPC4018NF-100M
Q301: NX6008NBKW; SOT323; ManufacturerPartNumber NX6008NBKW
R301, R302, R303, R304: 10kΩ; nominal-0402-1005; Tolerance ±1%; ManufacturerPartNumber WR04X1002FTL
R305, R306: 1kΩ; nominal-0402-1005; Tolerance ±1%; ManufacturerPartNumber WR04X1001FTL
R307, R309: 0Ω; nominal-0402-1005; Tolerance ±1%; ManufacturerPartNumber RC0402FR-070RL
R308: DNP; nominal-0402-1005; Tolerance ±1%
R310, R326, R327, R342, R343, R344: 33kΩ; nominal-0402-1005; Tolerance ±1%; ManufacturerPartNumber WR04X3302FTL
R311, R312, R313, R314, R315, R316, R317, R320, R321, R322, R323, R324, R325, R330, R331, R332, R333, R334: 43Ω; nominal-0402-1005; Tolerance ±1%; ManufacturerPartNumber RC0402FR-0743RL
R318, R319, R340, R341: 1.8kΩ; nominal-0402-1005; Tolerance ±1%; ManufacturerPartNumber RC0402FR-071K8L
R328, R329: 330Ω; nominal-0402-1005; Tolerance ±1%; ManufacturerPartNumber WR04X3300FTL
R335, R336, R337, R338, R339: 41.2Ω; nominal-0402-1005; Tolerance ±1%; ManufacturerPartNumber RC0402FR-0741R2L
R345: 5.1kΩ; nominal-0402-1005; Tolerance ±1%; ManufacturerPartNumber WR04X5101FTL
R346: 39kΩ; nominal-0402-1005; Tolerance ±1%; ManufacturerPartNumber RC0402FR-0739KL
TP301, TP302, TP303, TP304, TP305, TP306: testpoint-SP3050A-with-short-gnd
U301: PIC32CX1025SG41100-I/E5X; TQFP100-14x14mm-0.5mm; ManufacturerPartNumber PIC32CX1025SG41100-I/E5X
U302: AP22653AW6; SOT26; ManufacturerPartNumber AP22653AW6-7
XTAL301: 24MHz; 3225-1-3; Tolerance ±10ppm; ManufacturerPartNumber RH100-24.000-12-1010-EXT-TR
XTAL302: 8-48MHz; 3225-1-3; Tolerance ±10ppm
XTAL303: 32.768kHz; 3215; Tolerance ±20ppm; ManufacturerPartNumber DH2032K768C5T1521011

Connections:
/1-usb-and-power/CORE_VDD_MODE: R311.1; also elsewhere on the board
/1-usb-and-power/MCU.D+: U301.75 (USB.DP); also elsewhere on the board
/1-usb-and-power/MCU.D-: U301.74 (USB.DM); also elsewhere on the board
/1-usb-and-power/SCL: R319.2, TP302.1, U301.73 (SERCOM3.PAD[1]); also elsewhere on the board
/1-usb-and-power/SDA: R318.2, TP303.1, U301.72 (SERCOM3.PAD[0]); also elsewhere on the board
/1-usb-and-power/~CHARGER_DETECTED: U301.9 (PB04); also elsewhere on the board
/1-usb-and-power/~CHARGING_ALLOWED: U301.6 (PC03); also elsewhere on the board
/1-usb-and-power/~CORE_VDD_FAULT: U301.5 (EXTINT[2]); also elsewhere on the board
/1-usb-and-power/~HAS_DATA: U301.10 (PB05); also elsewhere on the board
/1-usb-and-power/~USB_PD_INT: U301.87 (EXTINT[11]); also elsewhere on the board
/1-usb-and-power/~USB_SUSPEND: R310.1, R326.1, R327.1, U301.4 (PC01); also elsewhere on the board
/2-msf-receiver/DS: U301.21 (PC05); also elsewhere on the board
/2-msf-receiver/MSF_OUT+: C323.2, C324.2, U301.15 (ADC0.AIN[2]); also elsewhere on the board
/2-msf-receiver/MSF_OUT-: C324.1, C325.2, U301.16 (ADC0.AIN[3]); also elsewhere on the board
/2-msf-receiver/MSF_RCV_EN: U301.17 (PA04); also elsewhere on the board
/2-msf-receiver/MSF_RCV_VREF_{+2.5V}: C322.1, U301.8 (VREFA); also elsewhere on the board
/2-msf-receiver/SHCP: U301.23 (PC07); also elsewhere on the board
/2-msf-receiver/STCP: U301.22 (PC06); also elsewhere on the board
/3-mcu-core/AMP_EN: U301.19 (PA06); also elsewhere on the board
/3-mcu-core/AMP_IN: U301.18 (DAC.VOUT[1]); also elsewhere on the board
/3-mcu-core/BC805M.MISO: R332.2; also elsewhere on the board
/3-mcu-core/BC805M.MOSI: R330.2; also elsewhere on the board
/3-mcu-core/BC805M.RXD: U301.53 (SERCOM1.PAD[1]); also elsewhere on the board
/3-mcu-core/BC805M.SCK: R331.2; also elsewhere on the board
/3-mcu-core/BC805M.SWDCLK: R329.2; also elsewhere on the board
/3-mcu-core/BC805M.SWDIO: R328.2; also elsewhere on the board
/3-mcu-core/BC805M.TXD: R334.2; also elsewhere on the board
/3-mcu-core/BC805M.~CTS: U301.55 (SERCOM1.PAD[3]); also elsewhere on the board
/3-mcu-core/BC805M.~RESET: U301.58 (SERCOM6.PAD[2]); also elsewhere on the board
/3-mcu-core/BC805M.~RTS: R333.2; also elsewhere on the board
/3-mcu-core/CLK: R320.2; also elsewhere on the board
/3-mcu-core/CMD: R321.2; also elsewhere on the board
/3-mcu-core/DAT0: R325.2; also elsewhere on the board
/3-mcu-core/DAT1: R324.2; also elsewhere on the board
/3-mcu-core/DAT2: R323.2; also elsewhere on the board
/3-mcu-core/DAT3: R322.2; also elsewhere on the board
/3-mcu-core/DATA0: R335.1; also elsewhere on the board
/3-mcu-core/DATA1: R336.1; also elsewhere on the board
/3-mcu-core/DATA2: R337.1; also elsewhere on the board
/3-mcu-core/DATA3: R338.1; also elsewhere on the board
/3-mcu-core/IR_RCV_DATA: R342.2, U301.46 (SERCOM4.PAD[1]); also elsewhere on the board
/3-mcu-core/MCU.SWDCLK: R303.1, U301.93 (CORTEX_CM4.SWDCLK); also elsewhere on the board
/3-mcu-core/MCU.SWDIO: R302.1, R313.2; also elsewhere on the board
/3-mcu-core/MCU.SWO: R301.1, R312.2; also elsewhere on the board
/3-mcu-core/MCU.TRACECLK: U301.85 (CORTEX_CM4.TRACECLK); also elsewhere on the board
/3-mcu-core/MCU.TRACEDATA0: R314.2; also elsewhere on the board
/3-mcu-core/MCU.TRACEDATA1: R315.2; also elsewhere on the board
/3-mcu-core/MCU.TRACEDATA2: R316.2; also elsewhere on the board
/3-mcu-core/MCU.TRACEDATA3: R317.2; also elsewhere on the board
/3-mcu-core/MCU.~RESET: R305.2, U301.88 (~RESET); also elsewhere on the board
/3-mcu-core/MCU_AV_{DD}: C311.1, C312.1, C313.1, C314.1, FB301.2 (P2_PWROUT), TP305.1, U301.12 (AV_{DD})
/3-mcu-core/MCU_V_{DDCORE}: C308.1, C309.1, C310.1, L301.2, TP304.1, U301.89 (V_{DDCORE})
/3-mcu-core/MCU_V_{SW}: L301.1, U301.91 (V_{SW})
/3-mcu-core/MCU_XOSC0_IN: C315.1, U301.48 (XOSC0.XIN), XTAL301.1
/3-mcu-core/MCU_XOSC0_OUT: R307.1, U301.49 (XOSC0.XOUT)
/3-mcu-core/MCU_XOSC1_IN: C317.1, U301.78 (XOSC1.XIN), XTAL302.1
/3-mcu-core/MCU_XOSC1_OUT: R308.1, U301.79 (XOSC1.XOUT)
/3-mcu-core/MCU_XOSC32K_IN: C319.1, U301.1 (XIN32), XTAL303.1
/3-mcu-core/MCU_XOSC32K_OUT: R309.1, U301.2 (XOUT32)
/3-mcu-core/PRX_GPIO0: U301.98 (PB01); also elsewhere on the board
/3-mcu-core/PRX_GPIO1: U301.97 (PB00); also elsewhere on the board
/3-mcu-core/SCK: R339.1; also elsewhere on the board
/3-mcu-core/SDCARD_EN: R343.1, R344.1, U301.45 (PC15), U302.3 (EN)
/3-mcu-core/SDCARD_V_{DD}: C327.1, C328.1, C329.1, C330.1, C331.1, C332.1, C333.1, C334.1, C335.1, C336.1, TP306.1, U302.6 (OUT); also elsewhere on the board
/3-mcu-core/TFT_BACKLED0: R341.1; also elsewhere on the board
/3-mcu-core/TFT_BACKLED1: R340.1; also elsewhere on the board
/3-mcu-core/TFT_I^{2}C_SEL: U301.42 (PC12); also elsewhere on the board
/3-mcu-core/TFT_QSPI_SEL: U301.41 (PC11); also elsewhere on the board
/3-mcu-core/TFT_TEAR0: U301.34 (EXTINT[12]); also elsewhere on the board
/3-mcu-core/TFT_TEAR1: U301.35 (EXTINT[13]); also elsewhere on the board
/3-mcu-core/TFT_TP_INT0: U301.43 (EXTINT[13]); also elsewhere on the board
/3-mcu-core/TFT_TP_INT1: U301.44 (EXTINT[14]); also elsewhere on the board
/3-mcu-core/~AMP_FAULT: U301.20 (PA07); also elsewhere on the board
/3-mcu-core/~BAR_INT: U301.99 (PB02); also elsewhere on the board
/3-mcu-core/~CD: R327.2, U301.64 (SDHC1.SDCD); also elsewhere on the board
/3-mcu-core/~HMD_ALERT: U301.100 (PB03); also elsewhere on the board
/3-mcu-core/~SDCARD_BUSYLED: Q301.3 (D); also elsewhere on the board
/3-mcu-core/~SDCARD_FAULT: R344.2, U301.13 (EXTINT[6]), U302.4 (~FAULT)
/3-mcu-core/~SS: U301.33 (QSPI.CS); also elsewhere on the board
/3-mcu-core/~TFT_RESET: U301.40 (PC10); also elsewhere on the board
/3-mcu-core/~WP: R326.2, U301.65 (SDHC1.SDWP); also elsewhere on the board
/CORE_VDD_{+3.3V}: C301.1, C302.1, C303.1, C304.1, C305.1, C306.1, C307.1, C326.1, C337.1, C338.1, C339.1, C340.1, C341.1, C342.1, C343.1, C344.1, C345.1, C346.1, C347.1, C348.1, C349.1, C350.1, FB301.1 (P1_PWRIN), R301.2, R302.2, R303.2, R304.1, R318.1, R319.1, R342.1, U301.25 (V_{DD}), U301.30 (V_{DD}), U301.39 (V_{DD}), U301.51 (V_{DD}), U301.63 (V_{DD}), U301.77 (V_{DD}), U301.92 (V_{DD}), U302.1 (IN); also elsewhere on the board
unnamed: C316.1, R307.2, XTAL301.3
unnamed: C318.1, R308.2, XTAL302.3
unnamed: C320.1, R309.2, XTAL303.2
unnamed: C321.1, R304.2, R305.1
unnamed: Q301.1 (G), R306.2
unnamed: R345.2, R346.1
unnamed: TP301.1, U301.7 (DAC.VOUT[0])
unnamed: R335.2, U301.26 (QSPI.DATA[0])
unnamed: R336.2, U301.27 (QSPI.DATA[1])
unnamed: R337.2, U301.28 (QSPI.DATA[2])
unnamed: R338.2, U301.29 (QSPI.DATA[3])
unnamed: R334.1, U301.52 (SERCOM1.PAD[0])
unnamed: R333.1, U301.54 (SERCOM1.PAD[2])
unnamed: R321.1, U301.70 (SDHC1.SDCMD)
unnamed: R320.1, U301.71 (SDHC1.SDCK)
unnamed: R313.1, U301.94 (CORTEX_CM4.SWDIO)
unnamed: R339.2, U301.32 (QSPI.SCK)
unnamed: R340.2, U301.36 (TC5.WO[0])
unnamed: R341.2, U301.37 (TC5.WO[1])
unnamed: R325.1, U301.66 (SDHC1.SDDAT[0])
unnamed: R324.1, U301.67 (SDHC1.SDDAT[1])
unnamed: R323.1, U301.68 (SDHC1.SDDAT[2])
unnamed: R322.1, U301.69 (SDHC1.SDDAT[3])
unnamed: R306.1, U301.81 (PB25)
unnamed: R312.1, U301.95 (CORTEX_CM4.SWO)
unnamed: R311.2, U301.96 (TC0.WO[1])
unnamed: R332.1, U301.56 (SERCOM6.PAD[0])
unnamed: R331.1, U301.57 (SERCOM6.PAD[1])
unnamed: R330.1, U301.59 (SERCOM6.PAD[3])
unnamed: R329.1, U301.60 (PC20)
unnamed: R328.1, U301.61 (PC21)
unnamed: R317.1, U301.82 (CORTEX_CM4.TRACEDATA[3])
unnamed: R316.1, U301.83 (CORTEX_CM4.TRACEDATA[2])
unnamed: R315.1, U301.84 (CORTEX_CM4.TRACEDATA[1])
unnamed: R314.1, U301.86 (CORTEX_CM4.TRACEDATA[0])
unnamed: R345.1, U302.5 (ILIMIT)

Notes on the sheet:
Fast-Mode I^{2}C (400kHz)
Current-Limited SD Card Supply
Use internal pull-downs on TF_TEARx pins to prevent floating interrupt lines in the event that the connector is pulled out
One bypass capacitor for each V_{DD} pin
Maximum DAC load is 5kΩ
R335-39
SD specification says that DAT lines are inputs during initialisation or idle; use MCU's internal pull-ups as they are under software control. The 50kΩ pull-up on DAT3, which is internal to the SD card, needs to be disabled via the SET_CLR_CARD_DETECT command after initialisation.
MCU Power Pins
Pins 5-20 are supplied by AV_{DD} so are preferably only digital inputs to keep noise out of the analogue domain. Slow-moving digital outputs are also OK, according to Microchip tech support
Pins 97-100 and 3-4 (page 57 of DS60001715G) need to be static to minimise XOSC32 jitter
Firmware to set unused pins as outputs
R330-34
R312-17
Calculations on page 1743 of DS60001715G; assuming 6.3pF and 5.9pF for pin parasitics
Make up to a total of 30x 4.7μF for the MCU_V_{DD} (CORE_VDD_{+3.3V}) rail. Spread around the board.
Unless otherwise specified: All resistors and capacitors are 0402 All resistors are ±1% 100ppm 0.625W thick-film All capacitors are ±20% X5R 10V MLCC
R340-41
Bypass Capacitors
R328-29
Calculations on page 1745 of DS60001715G; assuming 3.1pF and 3.2pF for pin parasitics. 17pF is closer to the ideal 12.5pF load but is a much less common value.
R320-25
Inductor specifications on page 1719 (REG_27,29,31) of DS60001715G
R301-3
Crystal Oscillators
483mA≤I_{max}≤639mA SD specification gives performance based on 1.44W to a UHS-I card; 0.72W for default speed

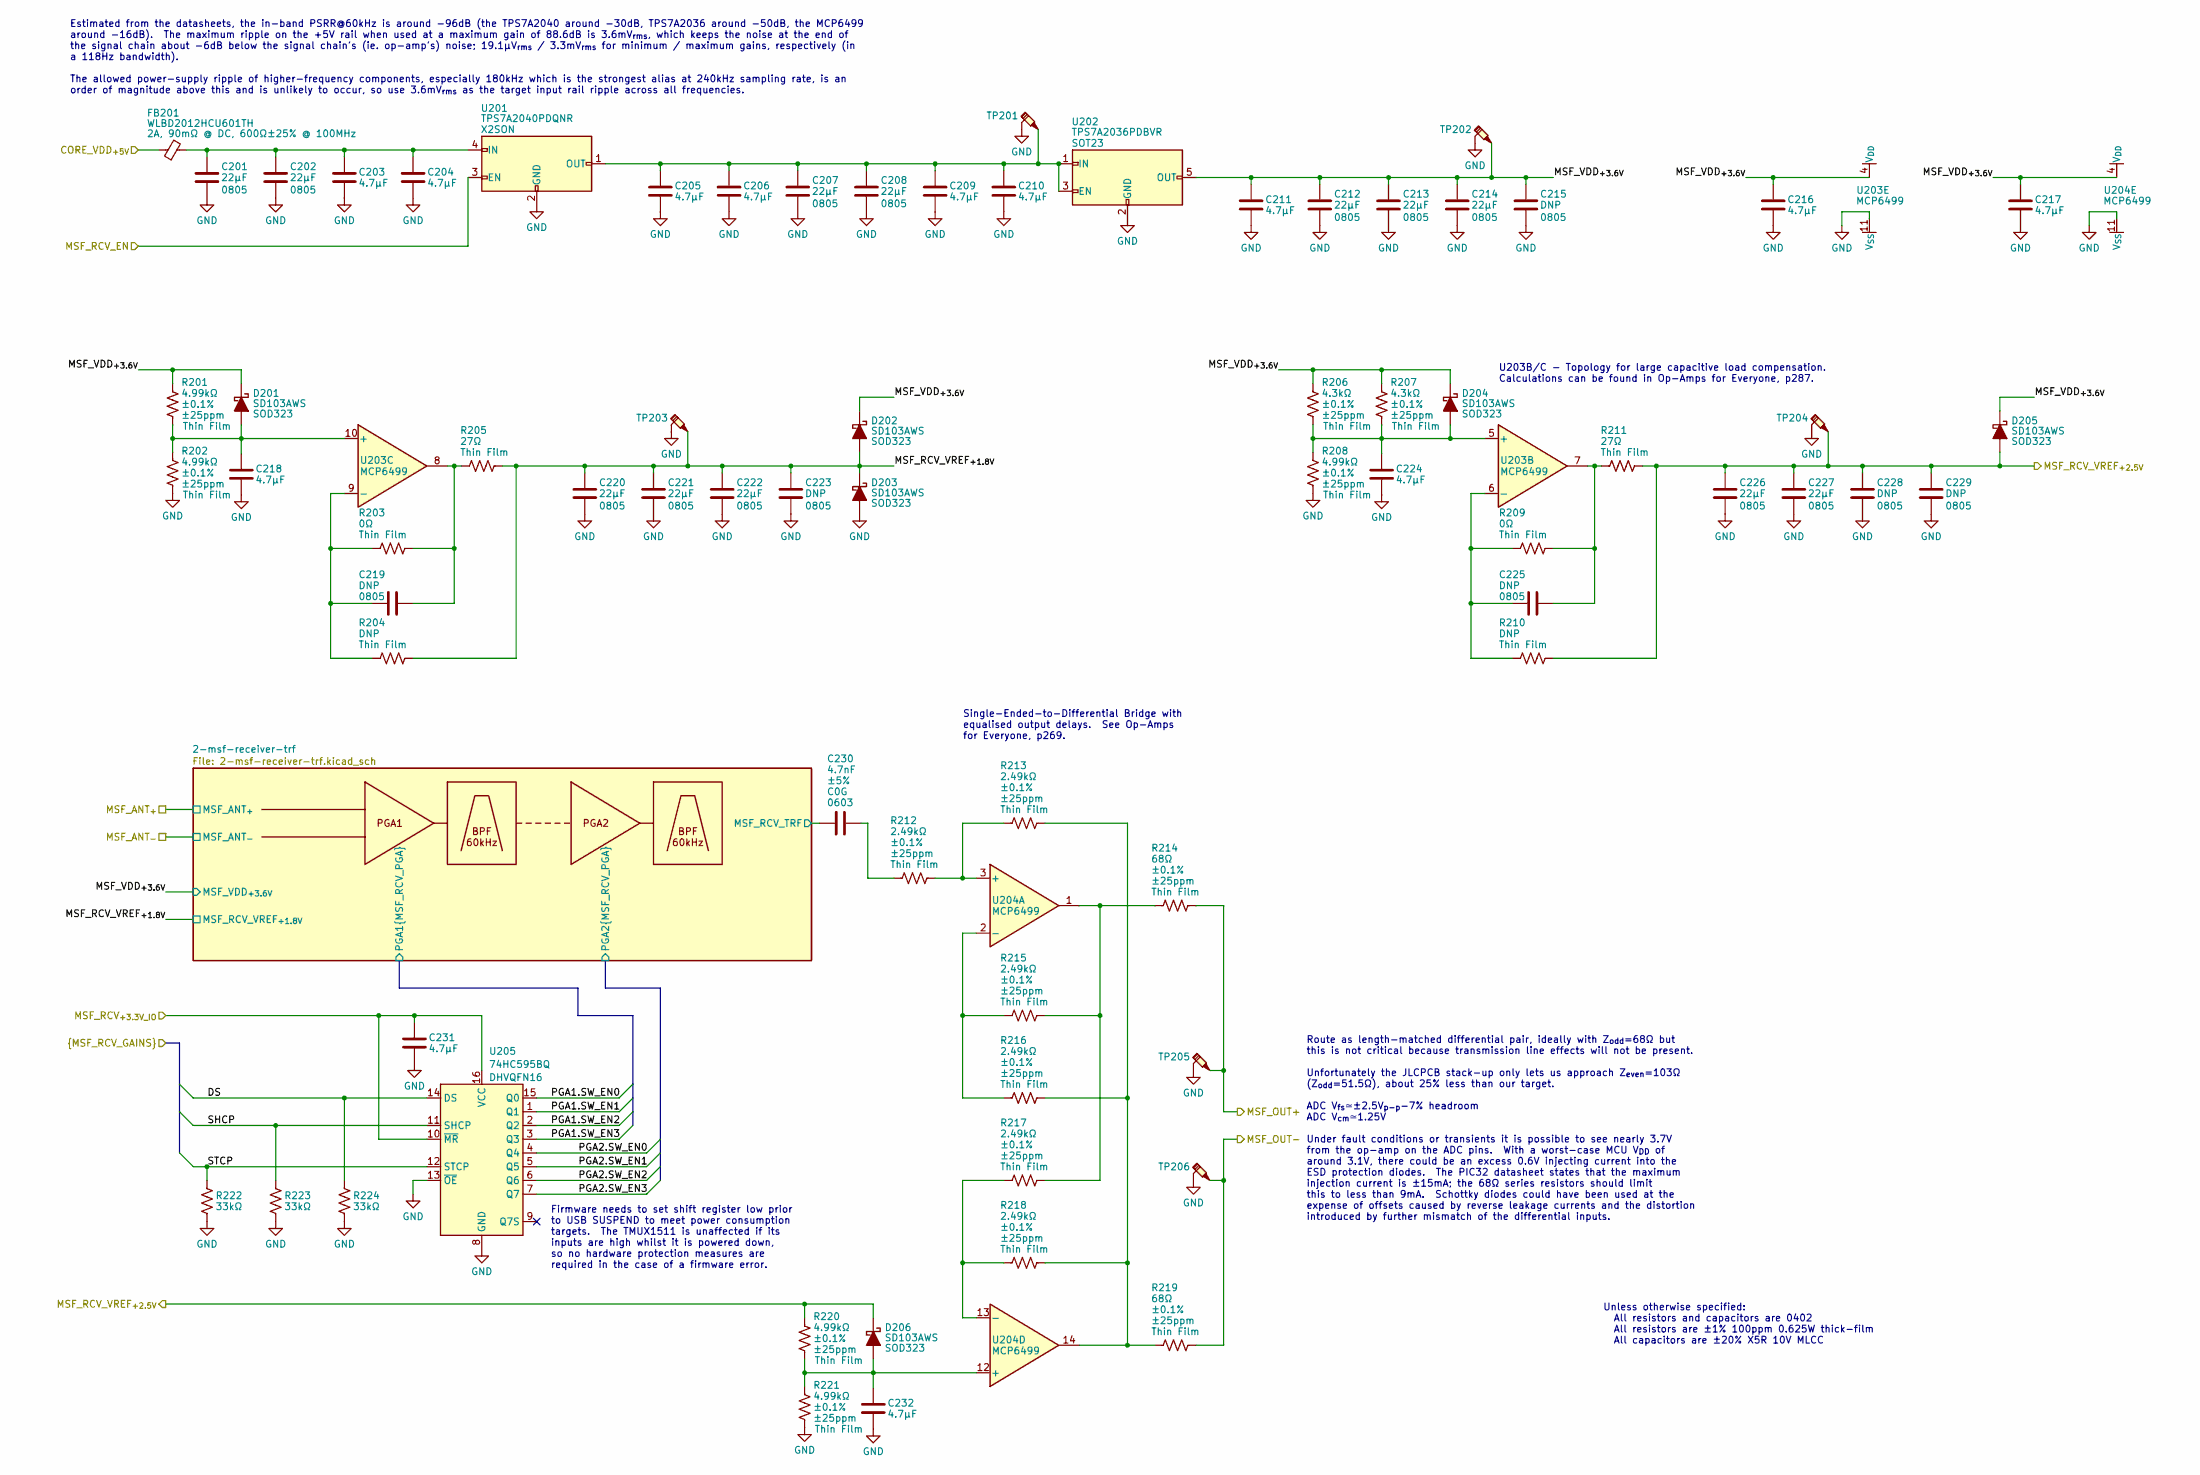
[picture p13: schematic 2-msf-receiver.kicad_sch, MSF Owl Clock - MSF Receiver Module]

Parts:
C201, C202, C207, C208, C212, C213, C214, C220, C221, C222, C226, C227: 22μF; unpolarised-nominal-0805-2012; Tolerance ±20%; VoltageRating 10V; ManufacturerPartNumber CL21A226MPQNNN
C203, C204, C205, C206, C209, C210, C211, C216, C217, C218, C224, C231, C232: 4.7μF; unpolarised-nominal-0402-1005; Tolerance ±20%; VoltageRating 10V; ManufacturerPartNumber CL05A475MP5NRNC
C215, C223, C228, C229: DNP; unpolarised-nominal-0805-2012; Tolerance ±20%; VoltageRating 10V; ManufacturerPartNumber CL21A226MPQNNN
C219, C225: DNP; unpolarised-nominal-0805-2012; Tolerance ±20%; VoltageRating 10V
C230: 4.7nF; unpolarised-nominal-0603-1608; Tolerance ±5%; VoltageRating 10V; ManufacturerPartNumber CC0603FRNPO9BN472
D201, D202, D203, D204, D205, D206: SD103AWS; SOD323; ManufacturerPartNumber SD103AWS
FB201: WLBD2012HCU601TH; WLBD2012; Tolerance ±25%; ManufacturerPartNumber WLBD2012HCU601TH
R201, R202, R208, R220, R221: 4.99kΩ; nominal-0402-1005; Tolerance ±0.1%; ManufacturerPartNumber RT0402BRD074K99L
R203, R209: 0Ω; nominal-0402-1005; Tolerance ±1%; ManufacturerPartNumber RC0402FR-070RL
R204, R210: DNP; nominal-0402-1005; Tolerance ±1%
R205, R211: 27Ω; nominal-0402-1005; Tolerance ±1%; ManufacturerPartNumber CPF0402B27RE1
R206, R207: 4.3kΩ; nominal-0402-1005; Tolerance ±0.1%; ManufacturerPartNumber RT0402BRD074K3L
R212, R213, R215, R216, R217, R218: 2.49kΩ; nominal-0402-1005; Tolerance ±0.1%; ManufacturerPartNumber RT0402BRD072K49L
R214, R219: 68Ω; nominal-0402-1005; Tolerance ±0.1%; ManufacturerPartNumber RT0402BRD0768RL
R222, R223, R224: 33kΩ; nominal-0402-1005; Tolerance ±1%; ManufacturerPartNumber WR04X3302FTL
SHEET201: (no value)
TP201, TP202, TP203, TP204, TP205, TP206: testpoint-SP3050A-with-short-gnd
U201: TPS7A2040PDQNR; X2SON4-1x1mm-0.65mm-expad-0.48x0.48mm; ManufacturerPartNumber TPS7A2040PDQNR
U202: TPS7A2036PDBVR; TPS7A20??PDBVR; ManufacturerPartNumber TPS7A2036PDBVR
U203, U204: MCP6499; SOIC14-3.9x8.65mm-1.27mm; ManufacturerPartNumber MCP6499T-E-SL
U205: 74HC595BQ; DHVQFN16-2.5x3.5mm-0.5mm-expad-2x1mm; ManufacturerPartNumber 74HC595BQ

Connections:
/1-usb-and-power/CORE_VDD_{+5V}: FB201.1 (P1_PWRIN); also elsewhere on the board
/2-msf-receiver/2-msf-receiver-trf/MSF_RCV_TRF: C230.2; also elsewhere on the board
/2-msf-receiver/2-msf-receiver-trf/PGA1.SW_EN0: U205.15 (Q0); also elsewhere on the board
/2-msf-receiver/2-msf-receiver-trf/PGA1.SW_EN1: U205.1 (Q1); also elsewhere on the board
/2-msf-receiver/2-msf-receiver-trf/PGA1.SW_EN2: U205.2 (Q2); also elsewhere on the board
/2-msf-receiver/2-msf-receiver-trf/PGA1.SW_EN3: U205.3 (Q3); also elsewhere on the board
/2-msf-receiver/2-msf-receiver-trf/PGA2.SW_EN0: U205.4 (Q4); also elsewhere on the board
/2-msf-receiver/2-msf-receiver-trf/PGA2.SW_EN1: U205.5 (Q5); also elsewhere on the board
/2-msf-receiver/2-msf-receiver-trf/PGA2.SW_EN2: U205.6 (Q6); also elsewhere on the board
/2-msf-receiver/2-msf-receiver-trf/PGA2.SW_EN3: U205.7 (Q7); also elsewhere on the board
/2-msf-receiver/DS: R224.1, U205.14 (DS); also elsewhere on the board
/2-msf-receiver/MSF_OUT+: R214.2, TP205.1; also elsewhere on the board
/2-msf-receiver/MSF_OUT-: R219.2, TP206.1; also elsewhere on the board
/2-msf-receiver/MSF_RCV_EN: U201.3 (EN); also elsewhere on the board
/2-msf-receiver/MSF_RCV_VREF_{+1.8V}: C220.1, C221.1, C222.1, C223.1, D202.2 (A), D203.1 (K), R204.2, R205.2, TP203.1; also elsewhere on the board
/2-msf-receiver/MSF_RCV_VREF_{+2.5V}: C226.1, C227.1, C228.1, C229.1, D205.2 (A), D206.1 (K), R210.2, R211.2, R220.1, TP204.1; also elsewhere on the board
/2-msf-receiver/MSF_VDD_{+3.6V}: C211.1, C212.1, C213.1, C214.1, C215.1, C216.1, C217.1, D201.1 (K), D202.1 (K), D204.1 (K), D205.1 (K), R201.1, R206.1, R207.1, TP202.1, U202.5 (OUT), U203.4 (V_{DD}), U204.4 (V_{DD}); also elsewhere on the board
/2-msf-receiver/SHCP: R223.1, U205.11 (SHCP); also elsewhere on the board
/2-msf-receiver/STCP: R222.1, U205.12 (STCP); also elsewhere on the board
/CORE_VDD_{+3.3V}: C231.1, U205.10 (~MR), U205.16 (VCC); also elsewhere on the board
unnamed: C219.2, R203.2, R205.1, U203.8
unnamed: C225.2, R209.2, R211.1, U203.7
unnamed: C230.1, R212.1
unnamed: C218.1, D201.2 (A), R201.2, R202.1, U203.10 (+)
unnamed: C224.1, D204.2 (A), R206.2, R207.2, R208.1, U203.5 (+)
unnamed: C232.1, D206.2 (A), R220.2, R221.1, U204.12 (+)
unnamed: C201.1, C202.1, C203.1, C204.1, FB201.2 (P2_PWROUT), U201.4 (IN)
unnamed: R213.2, R216.2, R218.2, R219.1, U204.14
unnamed: R214.1, R215.2, R217.2, U204.1
unnamed: C205.1, C206.1, C207.1, C208.1, C209.1, C210.1, TP201.1, U201.1 (OUT), U202.1 (IN), U202.3 (EN)
unnamed: C225.1, R209.1, R210.1, U203.6 (-)
unnamed: C219.1, R203.1, R204.1, U203.9 (-)
unnamed: R212.2, R213.1, U204.3 (+)
unnamed: R215.1, R216.1, U204.2 (-)
unnamed: R217.1, R218.1, U204.13 (-)

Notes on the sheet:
Estimated from the datasheets, the in-band PSRR@60kHz is around -96dB (the TPS7A2040 around -30dB, TPS7A2036 around -50dB, the MCP6499 around -16dB). The maximum ripple on the +5V rail when used at a maximum gain of 88.6dB is 3.6mV_{rms}, which keeps the noise at the end of the signal chain about -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
U203B/C - Topology for large capacitive load compensation. Calculations can be found in Op-Amps for Everyone, p287.
Route as length-matched differential pair, ideally with Z_{odd}=68Ω but this is not critical because transmission line effects will not be present. Unfortunately the JLCPCB stack-up only lets us approach Z_{even}=103Ω (Z_{odd}=51.5Ω), about 25% less than our target. ADC V_{fs}≃±2.5V_{p-p}-7% headro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
Unless otherwise specified: All resistors and capacitors are 0402 All resistors are ±1% 100ppm 0.625W thick-film All capacitors are ±20% X5R 10V MLCC
Firmware needs to set shift register low prior to USB SUSPEND to meet power consumption targets. The TMUX1511 is unaffected if its inputs are high whilst it is powered down, so no hardware protection measures are required in the case of a firmware error.
Single-Ended-to-Differential Bridge with equalised output delays. See Op-Amps for Everyone, p269.

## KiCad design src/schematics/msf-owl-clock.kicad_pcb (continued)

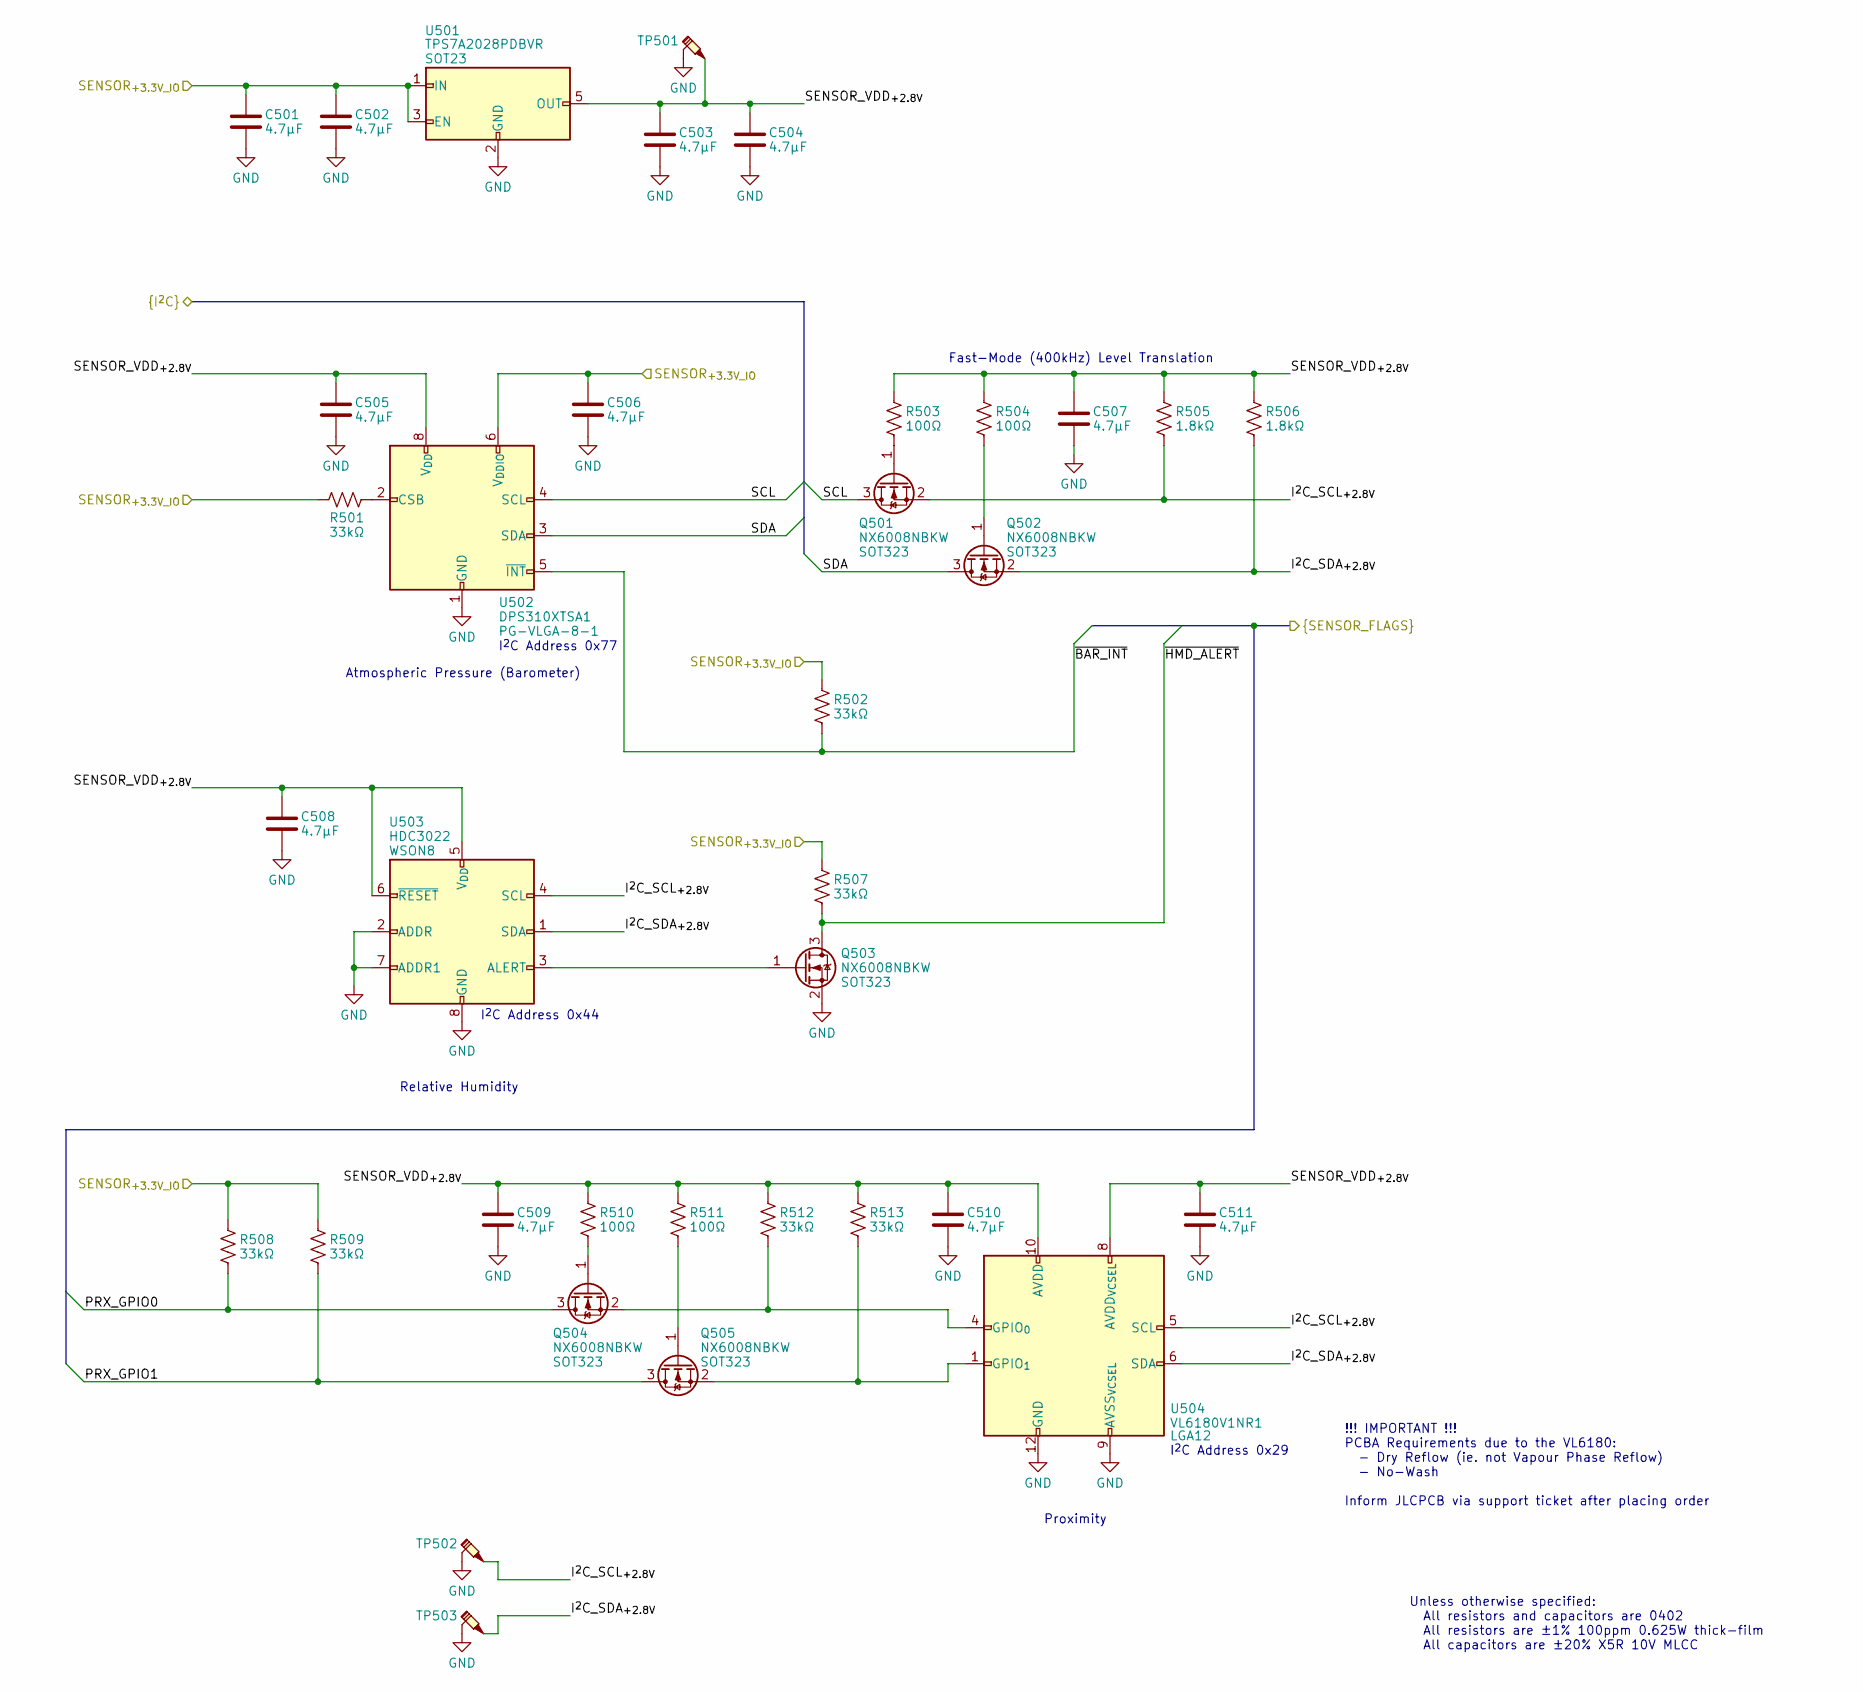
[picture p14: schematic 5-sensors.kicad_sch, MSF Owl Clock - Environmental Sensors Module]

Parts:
C501, C502, C503, C504, C505, C506, C507, C508, C509, C510, C511: 4.7μF; unpolarised-nominal-0402-1005; Tolerance ±20%; VoltageRating 10V; ManufacturerPartNumber CL05A475MP5NRNC
Q501, Q502, Q503, Q504, Q505: NX6008NBKW; SOT323; ManufacturerPartNumber NX6008NBKW
R501, R502, R507, R508, R509, R512, R513: 33kΩ; nominal-0402-1005; Tolerance ±1%; ManufacturerPartNumber WR04X3302FTL
R503, R504, R510, R511: 100Ω; nominal-0402-1005; Tolerance ±1%; ManufacturerPartNumber WR04X1000FTL
R505, R506: 1.8kΩ; nominal-0402-1005; Tolerance ±1%; ManufacturerPartNumber RC0402FR-071K8L
TP501, TP502, TP503: testpoint-SP3050A-with-short-gnd
U501: TPS7A2028PDBVR; TPS7A20??PDBVR; ManufacturerPartNumber TPS7A2028PDBVR
U502: DPS310XTSA1; PG-VLGA-8-1-2.0x2.5mm-0.65mm; ManufacturerPartNumber DPS310XTSA1
U503: HDC3022; WSON8-2.5x2.5mm-0.5mm-expad-1.2x1.9mm-thermvias; ManufacturerPartNumber HDC3022DEJR
U504: VL6180V1NR1; OPTICAL-LGA12-2.8x4.8mm-0.75mm; ManufacturerPartNumber VL6180V1NR1-1

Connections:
/1-usb-and-power/SCL: Q501.3 (D), U502.4 (SCL); also elsewhere on the board
/1-usb-and-power/SDA: Q502.3 (D), U502.3 (SDA); also elsewhere on the board
/3-mcu-core/PRX_GPIO0: Q504.3 (D), R508.2; also elsewhere on the board
/3-mcu-core/PRX_GPIO1: Q505.3 (D), R509.2; also elsewhere on the board
/3-mcu-core/~BAR_INT: R502.2, U502.5 (~INT); also elsewhere on the board
/3-mcu-core/~HMD_ALERT: Q503.3 (D), R507.2; also elsewhere on the board
/5-sensors/I^{2}C_SCL_{+2.8V}: Q501.2 (S), R505.2, TP502.1, U503.4 (SCL), U504.5 (SCL)
/5-sensors/I^{2}C_SDA_{+2.8V}: Q502.2 (S), R506.2, TP503.1, U503.1 (SDA), U504.6 (SDA)
/5-sensors/SENSOR_VDD_{+2.8V}: C503.1, C504.1, C505.1, C507.1, C508.1, C509.1, C510.1, C511.1, R503.1, R504.1, R505.1, R506.1, R510.1, R511.1, R512.1, R513.1, TP501.1, U501.5 (OUT), U502.8 (V_{DD}), U503.5 (V_{DD}), U503.6 (~RESET), U504.8 (AVDD_{VCSEL}), U504.10 (AVDD)
/CORE_VDD_{+3.3V}: C501.1, C502.1, C506.1, R501.1, R502.1, R507.1, R508.1, R509.1, U501.1 (IN), U501.3 (EN), U502.6 (V_{DDIO}); also elsewhere on the board
unnamed: Q501.1 (G), R503.2
unnamed: Q502.1 (G), R504.2
unnamed: Q503.1 (G), U503.3 (ALERT)
unnamed: Q504.1 (G), R510.2
unnamed: Q504.2 (S), R512.2, U504.4 (GPIO_{0})
unnamed: Q505.1 (G), R511.2
unnamed: Q505.2 (S), R513.2, U504.1 (GPIO_{1})
unnamed: R501.2, U502.2 (CSB)

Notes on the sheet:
Fast-Mode (400kHz) Level Translation
Unless otherwise specified: All resistors and capacitors are 0402 All resistors are ±1% 100ppm 0.625W thick-film All capacitors are ±20% X5R 10V MLCC
I^{2}C Address 0x77
I^{2}C Address 0x44
!!! IMPORTANT !!! PCBA Requirements due to the VL6180: - Dry Reflow (ie. not Vapour Phase Reflow) - No-Wash Inform JLCPCB via support ticket after placing order
Proximity
I^{2}C Address 0x29
Relative Humidity
Atmospheric Pressure (Barometer)

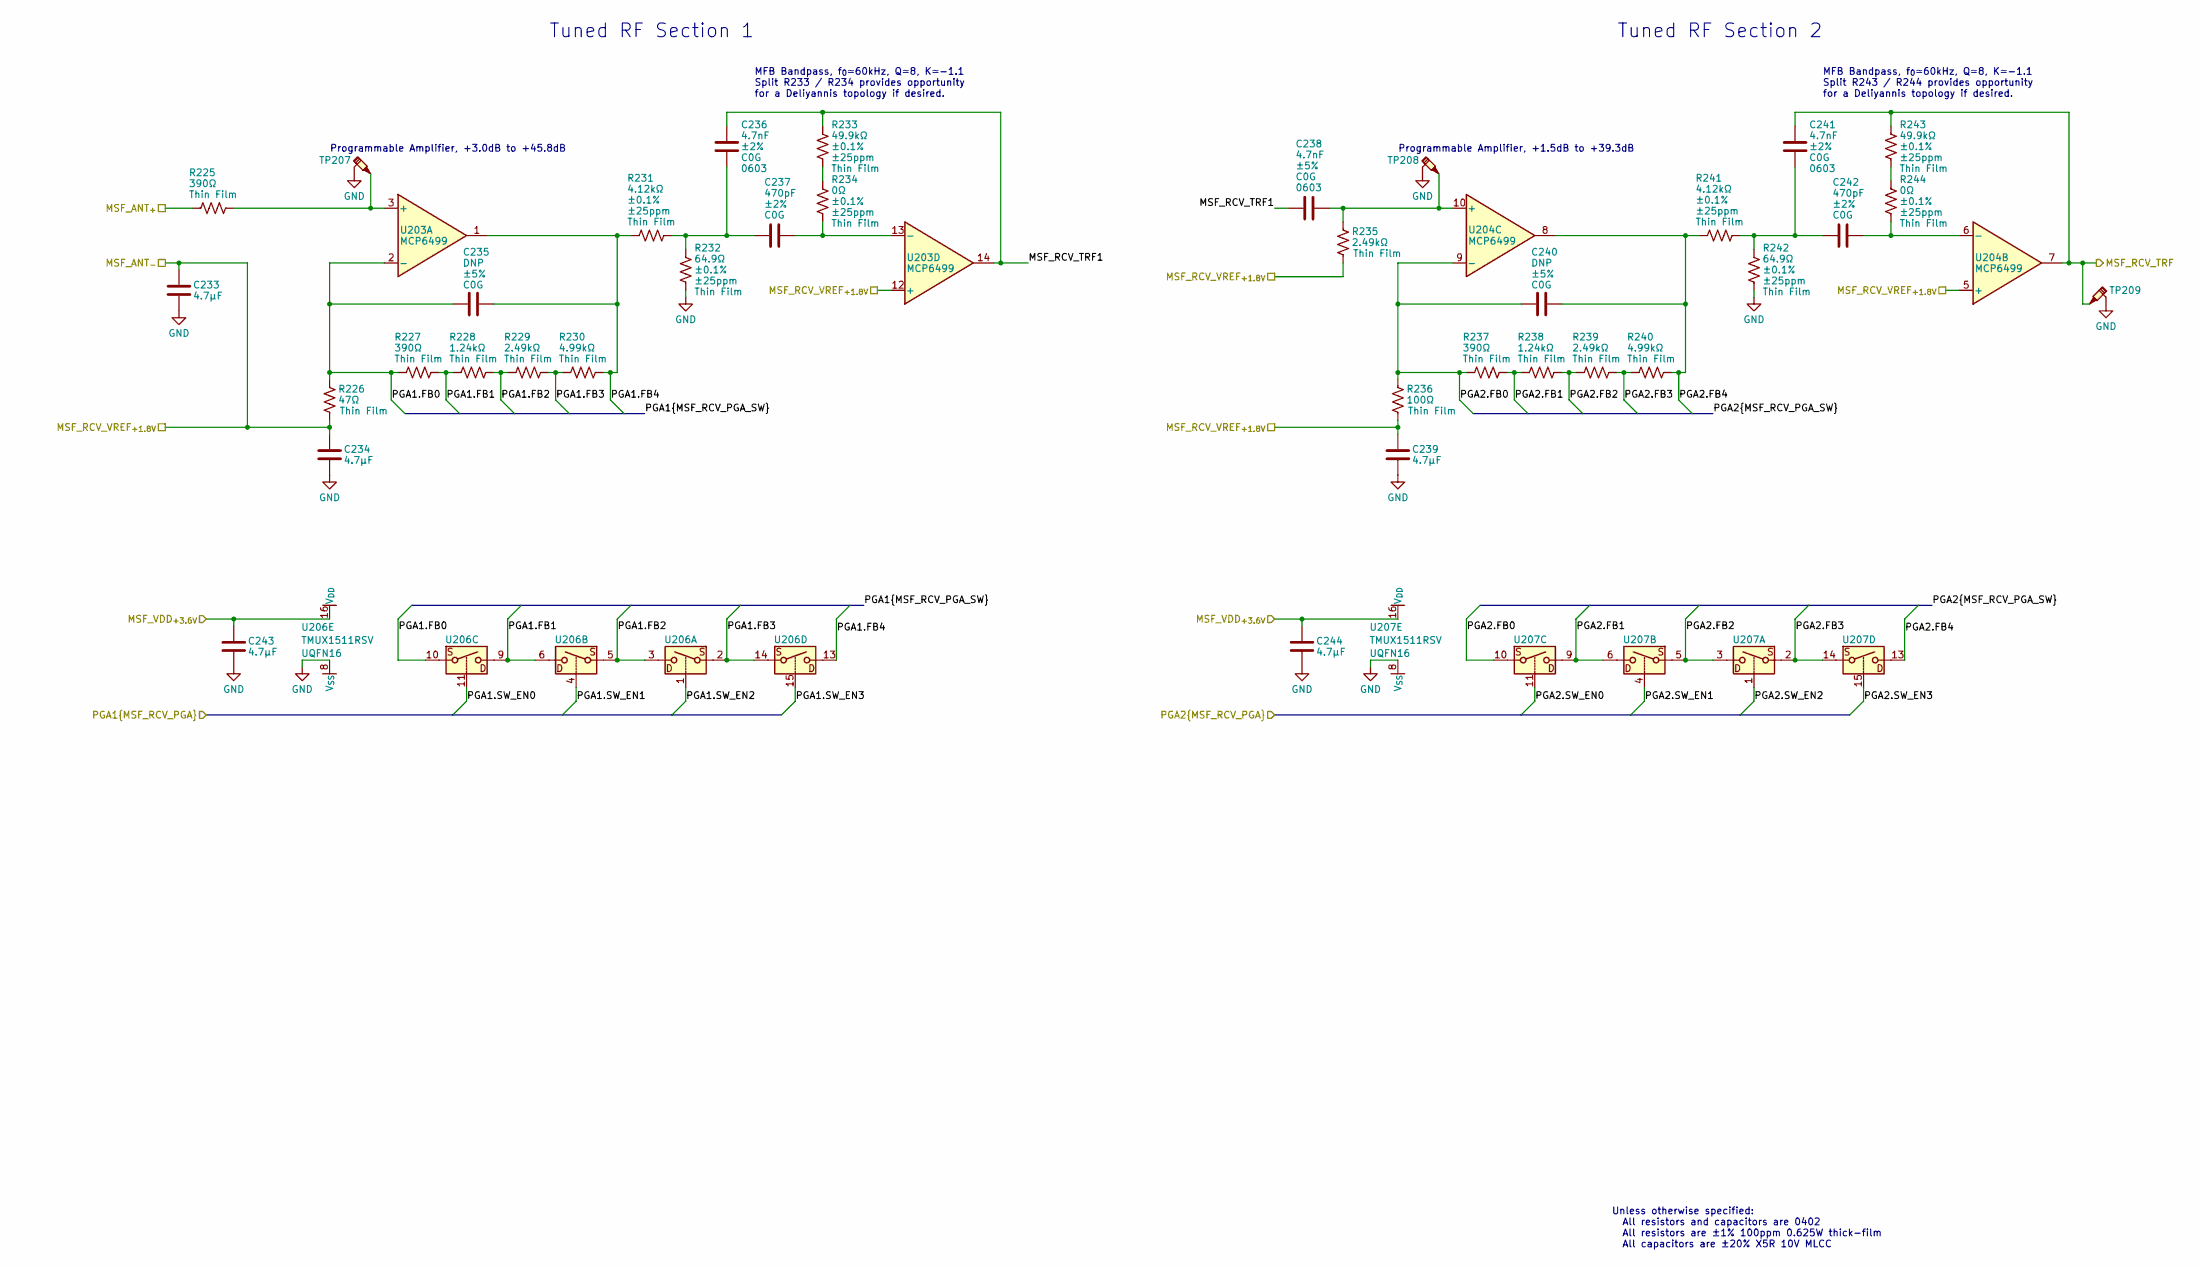
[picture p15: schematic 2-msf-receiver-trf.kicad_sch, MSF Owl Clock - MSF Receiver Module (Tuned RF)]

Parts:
C233, C234, C239, C243, C244: 4.7μF; unpolarised-nominal-0402-1005; Tolerance ±20%; VoltageRating 10V; ManufacturerPartNumber CL05A475MP5NRNC
C235, C240: DNP; unpolarised-nominal-0402-1005; Tolerance ±5%; VoltageRating 10V
C236, C241: 4.7nF; unpolarised-nominal-0603-1608; Tolerance ±2%; VoltageRating 10V; ManufacturerPartNumber CC0603FRNPO9BN472
C237, C242: 470pF; unpolarised-nominal-0402-1005; Tolerance ±2%; VoltageRating 10V; ManufacturerPartNumber GCM1555C1H471FA16D
C238: 4.7nF; unpolarised-nominal-0603-1608; Tolerance ±5%; VoltageRating 10V; ManufacturerPartNumber CC0603FRNPO9BN472
R225, R227, R237: 390Ω; nominal-0402-1005; Tolerance ±1%; ManufacturerPartNumber RT0402BRD07390RL
R226: 47Ω; nominal-0402-1005; Tolerance ±1%; ManufacturerPartNumber ERA-2AEB470X
R228, R238: 1.24kΩ; nominal-0402-1005; Tolerance ±1%; ManufacturerPartNumber RT0402BRD071K24L
R229, R235, R239: 2.49kΩ; nominal-0402-1005; Tolerance ±1%; ManufacturerPartNumber RT0402BRD072K49L
R230, R240: 4.99kΩ; nominal-0402-1005; Tolerance ±1%; ManufacturerPartNumber RT0402BRD074K99L
R231, R241: 4.12kΩ; nominal-0402-1005; Tolerance ±0.1%; ManufacturerPartNumber RT0402BRD074K12L
R232, R242: 64.9Ω; nominal-0402-1005; Tolerance ±0.1%; ManufacturerPartNumber RP73PF1E64R9BTD
R233, R243: 49.9kΩ; nominal-0402-1005; Tolerance ±0.1%; ManufacturerPartNumber RT0402BRD0749K9L
R234, R244: 0Ω; nominal-0402-1005; Tolerance ±0.1%; ManufacturerPartNumber RC0402FR-070RL
R236: 100Ω; nominal-0402-1005; Tolerance ±1%; ManufacturerPartNumber RT0402BRD07100RL
TP207, TP208, TP209: testpoint-SP3050A-with-short-gnd
U203, U204: MCP6499; SOIC14-3.9x8.65mm-1.27mm; ManufacturerPartNumber MCP6499T-E-SL
U206, U207: TMUX1511RSV; UQFN16-1.8x2.6mm-0.4mm; ManufacturerPartNumber TMUX1511RSVR

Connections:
/2-msf-receiver/2-msf-receiver-trf/MSF_RCV_TRF: C241.2, R243.1, TP209.1, U204.7; also elsewhere on the board
/2-msf-receiver/2-msf-receiver-trf/MSF_RCV_TRF1: C236.2, C238.2, R233.1, U203.14
/2-msf-receiver/2-msf-receiver-trf/PGA1.FB0: C235.1, R226.1, R227.1, U203.2 (-), U206.10
/2-msf-receiver/2-msf-receiver-trf/PGA1.FB1: R227.2, R228.1, U206.6, U206.9
/2-msf-receiver/2-msf-receiver-trf/PGA1.FB2: R228.2, R229.1, U206.3, U206.5
/2-msf-receiver/2-msf-receiver-trf/PGA1.FB3: R229.2, R230.1, U206.2, U206.14
/2-msf-receiver/2-msf-receiver-trf/PGA1.FB4: C235.2, R230.2, R231.1, U203.1, U206.13
/2-msf-receiver/2-msf-receiver-trf/PGA1.SW_EN0: U206.11; also elsewhere on the board
/2-msf-receiver/2-msf-receiver-trf/PGA1.SW_EN1: U206.4; also elsewhere on the board
/2-msf-receiver/2-msf-receiver-trf/PGA1.SW_EN2: U206.1; also elsewhere on the board
/2-msf-receiver/2-msf-receiver-trf/PGA1.SW_EN3: U206.15; also elsewhere on the board
/2-msf-receiver/2-msf-receiver-trf/PGA2.FB0: C240.1, R236.1, R237.1, U204.9 (-), U207.10
/2-msf-receiver/2-msf-receiver-trf/PGA2.FB1: R237.2, R238.1, U207.6, U207.9
/2-msf-receiver/2-msf-receiver-trf/PGA2.FB2: R238.2, R239.1, U207.3, U207.5
/2-msf-receiver/2-msf-receiver-trf/PGA2.FB3: R239.2, R240.1, U207.2, U207.14
/2-msf-receiver/2-msf-receiver-trf/PGA2.FB4: C240.2, R240.2, R241.1, U204.8, U207.13
/2-msf-receiver/2-msf-receiver-trf/PGA2.SW_EN0: U207.11; also elsewhere on the board
/2-msf-receiver/2-msf-receiver-trf/PGA2.SW_EN1: U207.4; also elsewhere on the board
/2-msf-receiver/2-msf-receiver-trf/PGA2.SW_EN2: U207.1; also elsewhere on the board
/2-msf-receiver/2-msf-receiver-trf/PGA2.SW_EN3: U207.15; also elsewhere on the board
/2-msf-receiver/MSF_ANT_{+}: R225.1; also elsewhere on the board
/2-msf-receiver/MSF_RCV_VREF_{+1.8V}: C233.1, C234.1, C239.1, R226.2, R235.2, R236.2, U203.12 (+), U204.5 (+); also elsewhere on the board
/2-msf-receiver/MSF_VDD_{+3.6V}: C243.1, C244.1, U206.16 (V_{DD}), U207.16 (V_{DD}); also elsewhere on the board
unnamed: C236.1, C237.1, R231.2, R232.1
unnamed: C241.1, C242.1, R241.2, R242.1
unnamed: R233.2, R234.1
unnamed: R243.2, R244.1
unnamed: R225.2, TP207.1, U203.3 (+)
unnamed: C237.2, R234.2, U203.13 (-)
unnamed: C242.2, R244.2, U204.6 (-)
unnamed: C238.1, R235.1, TP208.1, U204.10 (+)

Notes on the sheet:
Programmable Amplifier, +1.5dB to +39.3dB
Tuned RF Section 2
Unless otherwise specified: All resistors and capacitors are 0402 All resistors are ±1% 100ppm 0.625W thick-film All capacitors are ±20% X5R 10V MLCC
Tuned RF Section 1
MFB Bandpass, f_{0}≃60kHz, Q≃8, K≃-1.1 Split R243 / R244 provides opportunity for a Deliyannis topology if desired.
Programmable Amplifier, +3.0dB to +45.8dB
MFB Bandpass, f_{0}≃60kHz, Q≃8, K≃-1.1 Split R233 / R234 provides opportunity for a Deliyannis topology if desired.

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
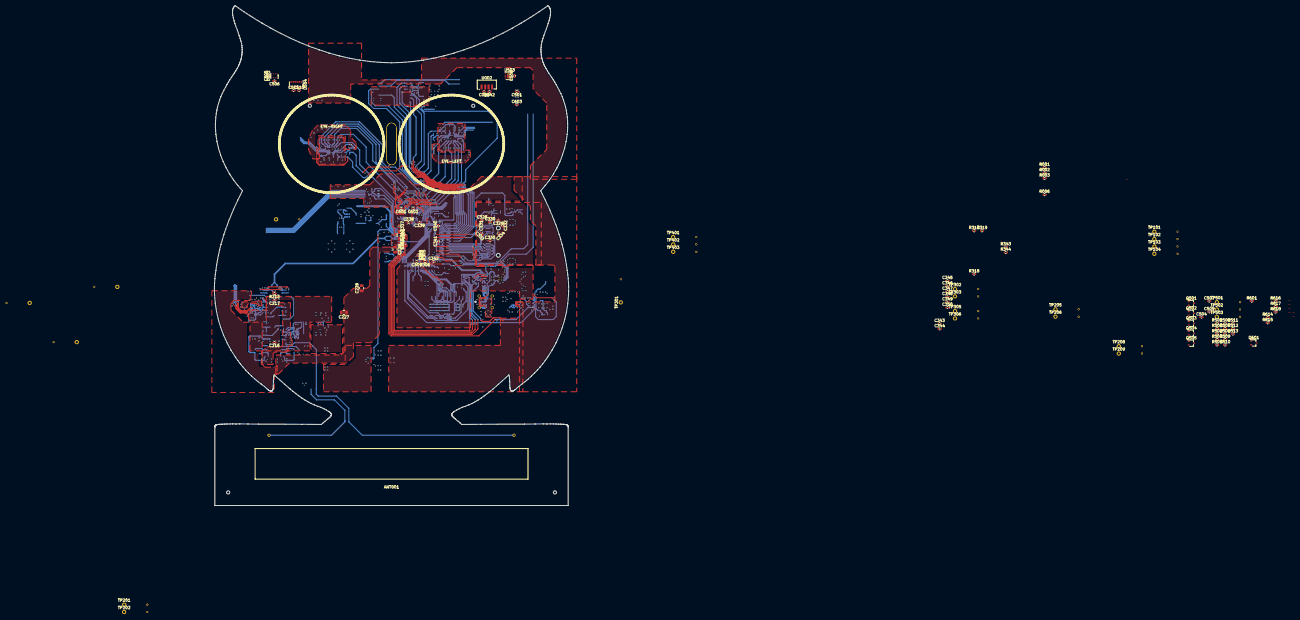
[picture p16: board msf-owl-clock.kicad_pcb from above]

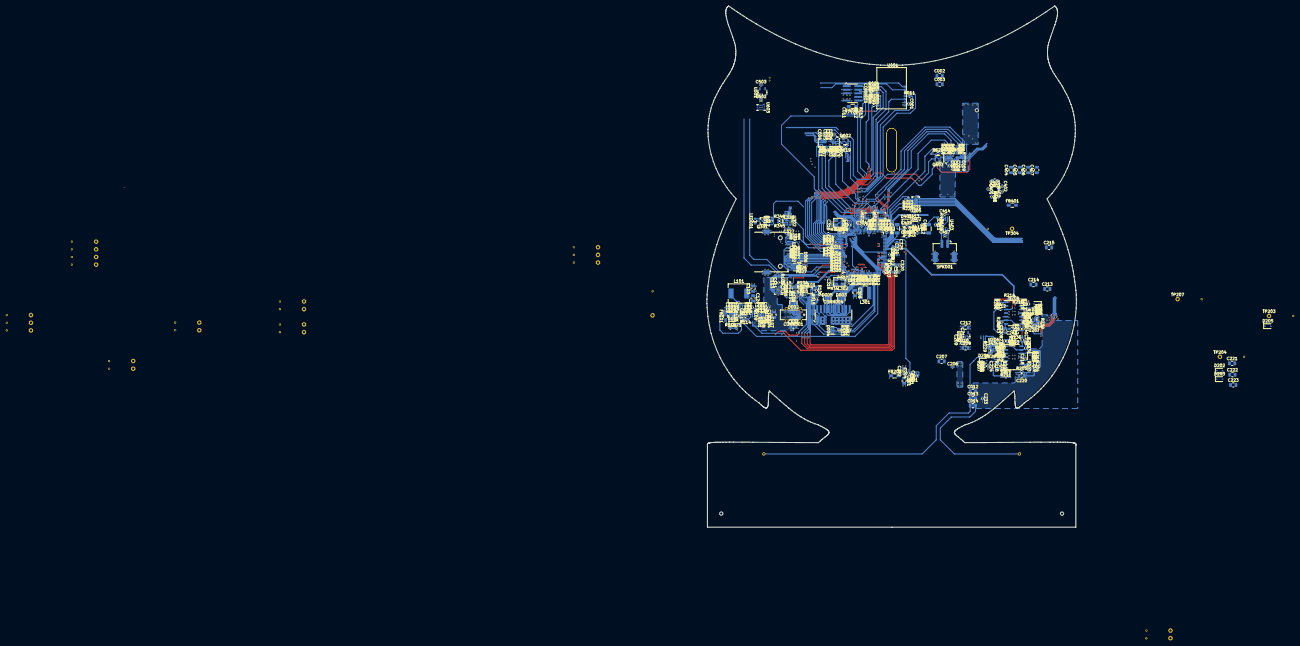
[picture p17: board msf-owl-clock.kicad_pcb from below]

Board: 4 copper layers, 130.1 x 183.6 mm, 443 parts (321 on the bottom side), 256 nets.

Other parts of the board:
EYE-LEFT: er-tft1.32-1-eye
EYE-RIGHT: er-tft1.32-1-eye
NT609, NT610: Net Tie; net-tie-2-6mil
TALON-LEFT: talon
TALON-RIGHT: talon

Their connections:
/1-usb-and-power/CORE_VDD_{+5V}: NT609.1 (P1_PWRIN), NT610.1 (P1_PWRIN); also elsewhere on the board

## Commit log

2023-12-28 Initial set of datasheets, articles and design calculations.
    [DesignCalculations.ods]
2023-12-28 Added a SPICE simulation for the MSF receiver.
    [msf-front-end.kicad_pcb, msf-front-end.kicad_sch]
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2024-01-01 Started to put the schematics together, mainly around defining and joining the logical blocks, along with the PIC32 pin and peripheral mapping. Lots of notes and some new datasheets / specifications.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
    [1-usb-and-power.kicad_sch, 2-msf-receiver.kicad_sch, 3-mcu-core.kicad_sch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]
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2024-01-06 Added a simulation to verify I2C level shifting.
    [i2c-level-shifting.kicad_pcb, i2c-level-shifting.kicad_sch]
2024-01-06 Further elaboration of the design, particularly around the power budget. It's clear that the USB Suspend current of 2.5mA won't be met, mainly due to the DPS1133 power switch's quiescent current. Thi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
    [1-usb-and-power.kicad_sch, 3-mcu-core.kicad_sch, 5-sensors.kicad_sch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]
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2024-01-12 Various calculations and simulations around the power supply decoupling networks. Still WIP but some good progress has been made in the direction of ballpark numbers; I can't hope to simulate any of 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
    [DesignCalculations.ods, power-bypass-caps.kicad_pcb, power-bypass-caps.kicad_sch]
2024-01-19 Added a simulation for modelling USB inrush current.
    [DesignCalculations.ods, usb-inrush.kicad_pcb, usb-inrush.kicad_sch]
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2024-01-21 Further elaboration of the design and schematics, mainly power supply calculations.
    [1-usb-and-power.kicad_sch, 2-msf-receiver.kicad_sch, 3-mcu-core.kicad_sch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]
2024-01-23 Started to draw the USB / power input module.
    [1-usb-and-power.kicad_sch, 3-mcu-core.kicad_sch, DesignCalculations.ods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]
2024-01-28 Further elaboration of the USB / Power schematic.
    [1-usb-and-power.kicad_sch, 3-mcu-core.kicad_sch, 6-tft-driver.kicad_sch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]
2024-02-10 Initial stab at a simulation for the buck regulator. Started to flesh out the USB / power schematics. More work required to figure out the large ripple on the buck regulator's input, which looks to b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
    [1-usb-and-power.kicad_sch, 3-mcu-core.kicad_sch, DesignCalculations.ods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]
2024-02-14 Further elaboration of the USB / power module schematics.
    [1-usb-and-power.kicad_sch, 2-msf-receiver.kicad_sch, 4-audio-out.kicad_sch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]
2024-02-21 Started to explore active filtering rather than using crystals for the MSF front-end.
    [msf-front-end.kicad_sch]
2024-02-21 Started to add some calculations around the MSF front-end but realised the specs are probably too restrictive / ambitious for a simple design. The outcome of the active filtering simulations may be m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
    [DesignCalculations.ods]
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2024-02-22 Tidied up the MSF front-end simulation. Next step - Monte Carlo...
    [msf-front-end.kicad_sch]
2024-02-24 Added a Monte-Carlo simulation to verify the MSF front-end over component variations.
    [msf-front-end.kicad_sch]
2024-02-24 Added a TODO as a reminder not to forget about discharging the reference rails on power-down.
    [2-msf-receiver.kicad_sch]
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2024-02-27 Ran the Monte-Carlo and transient simulations for the MSF front-end. A decent first stab - noise analysis next.
    [msf-front-end.kicad_sch]
2024-02-28 Investigations around noise for the MSF front-end. WIP.
    [msf-front-end.kicad_sch]
2024-03-04 Lots of faffing around trying to get ngspice to (reliably) converge for the MSF front-end, particularly around the Monte-Carlo simulations which seem to diverge for some values - it even appears as t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
    [2-msf-receiver.kicad_sch, DesignCalculations.ods, msf-front-end.kicad_sch]
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2024-03-10 Re-running some simulations. Plus fixed a capacitor model that was biased for 1.25V when really it ought to have been 1.8V based on the in-circuit voltage.
    [msf-front-end.kicad_sch]
2024-03-11 Added a simple simulation to verify the voltage references and their discharges behave when the +3.6V rail is cut.
    [vref.kicad_pcb, vref.kicad_sch]
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2024-03-19 Investigated the effect of some bypass networks on the op-amp outputs (PSRR).
    [DesignCalculations.ods, msf-front-end.kicad_sch]
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2024-03-22 Started drawing up the audio output schematic. Added a simulation to verify the DAC reconstruction filter.
    [4-audio-out.kicad_sch, DesignCalculations.ods, audio-dac-filter.kicad_pcb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]
2024-03-23 Finished drawing up the audio output schematic. The speaker selection is still to do.
    [1-usb-and-power.kicad_sch, 2-msf-receiver-trf.kicad_sch, 2-msf-receiver.kicad_sch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]
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2024-03-23 Corrected the shutdown current for the TPS7A2040.
    [DesignCalculations.ods]
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2024-03-26 Added gate resistors to reduce di/dt and thus supply noise.
    [5-sensors.kicad_sch, i2c-level-shifting.kicad_sch]
2024-03-26 Replaced MMBT3904 with NX6008 to reduce distinct part count.
    [3-mcu-core.kicad_sch]
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2024-04-04 Further elaboration of the circuitry surrounding the microcontroller. Plus a few typos / tidy-ups.
    [2-msf-receiver-trf.kicad_sch, 3-mcu-core.kicad_sch, 5-sensors.kicad_sch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]
2024-04-15 Added a (rough-and-ready) simulation for sense-checking the number of bypass capacitors required on the various VDD rails. It's all very approximate and really needs to be examined on the bench, but 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
    [mcu-vdd-rail.kicad_pcb, mcu-vdd-rail.kicad_sch]
2024-04-16 Various tidy-ups and checks, mainly around the bypass capacitors. Added a load of test points.
    [1-usb-and-power.kicad_sch, 2-msf-receiver-trf.kicad_sch, 2-msf-receiver.kicad_sch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]
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2024-04-18 Added footprints for the ARM debug connectors. Added a datasheet for the speaker connector (Molex 502443-0270).
    [msf-owl-clock.kicad_sch]
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2024-04-18 Fixed the orientation of the TSOP75338TT.
    [msf-owl-clock.kicad_sch]
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2024-04-20 Added a 3D model for the ferrite rod antenna; unfortunately OpenSCAD CSG export does not correctly transform into STEP so FreeCAD had to be leveraged also.
    [ferrite-rod-antenna.FCStd, ferrite-rod-antenna.scad, ferrite-rod-antenna.step]
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2024-04-21 Some footprint / net bugfixes identified whilst generating the initial PCB.
    [1-usb-and-power.kicad_sch, 2-msf-receiver.kicad_sch, 4-audio-out.kicad_sch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]
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2024-04-23 Simplified the owl PCB outline, made it more symmetrical, and closed the shape correctly so that it acts as a proper board edge.
    [msf-owl-clock.kicad_pcb]
2024-04-23 Fixed the footprint type for the ferrite rod antenna.
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2024-04-24 Added a DRC rule to set the board-to-fill distance independently of the [via|track|whatever]-to-fill distance.
    [msf-owl-clock.kicad_pcb]
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2024-04-24 Finalised the location and dimensions of the eyes and their connectors; based on bench measurements.
    [msf-owl-clock.kicad_pcb]
2024-04-24 Added tie-wrap holes for the talons, along with a 3D model of the tie-wraps.
    [msf-owl-clock.kicad_pcb, talon.FCStd, talon.scad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]
2024-04-24 FreeCAD project files are binaries; dropped a bit of a bollock and lost the (uncorrupted) original of the ferrite rod antenna whilst trying to rectify. Re-generated from the STEP and re-committed.
    [ferrite-rod-antenna.FCStd]
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2024-04-28 Removed free-floating vias in favour of locking them to their given nets - should result in fewer errors caused by accidentally touching them with different nets.
    [msf-owl-clock.kicad_pcb]
2024-05-03 PCB routing - trying to find the best placement in relation to the radio, regulators and speaker driver.
    [msf-owl-clock.kicad_pcb]
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2024-05-09 Updated to allow up to 1.44W for the SD card, which is actually what UHS-I specifications are measured at; 0.72W is the limit for the default speed mode / driver strength.
    [1-usb-and-power.kicad_sch, 3-mcu-core.kicad_sch, DesignCalculations.ods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]
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2024-06-09 PCB routing. Fixed most of the DRC violations.
    [1-usb-and-power.kicad_sch, 2-msf-receiver-trf.kicad_sch, 2-msf-receiver.kicad_sch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]
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2024-06-13 Generated all of the gerbers, drills, centroids and BOMs. Also generated a PDF of the schematics, although there's a Z-order bug in KiCAD that blanks some pin names out; will need to see if that can 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
    [msf-owl-clock-B_Cu.gbl, msf-owl-clock-B_Fab.gbr, msf-owl-clock-B_Mask.gbs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]
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2024-07-11 Final push to JLCPCB. Fixed various component rotation mismatches, some silkscreen issues, BOM amendments due to component availability, etc.
    [1-usb-and-power.kicad_sch, 2-msf-receiver-trf.kicad_sch, 2-msf-receiver.kicad_sch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]
2024-07-23 Added some photographs of the board and a basic README. Regenerated the PDF schematics since KiCAD doesn't print the boxes (hierarchical sheet symbols) correctly. They're still not right, but at leas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
